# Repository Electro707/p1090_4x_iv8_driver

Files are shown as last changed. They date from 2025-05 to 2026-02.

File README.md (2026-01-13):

# P1090 - IV-8 Driver, 4x
\> PCBs (both), Rev 1
\> Firmware, Rev 1A (wip)
\> Enclosure, Rev 1

This project is a driver for 4xIV-8 VFD Tubes.

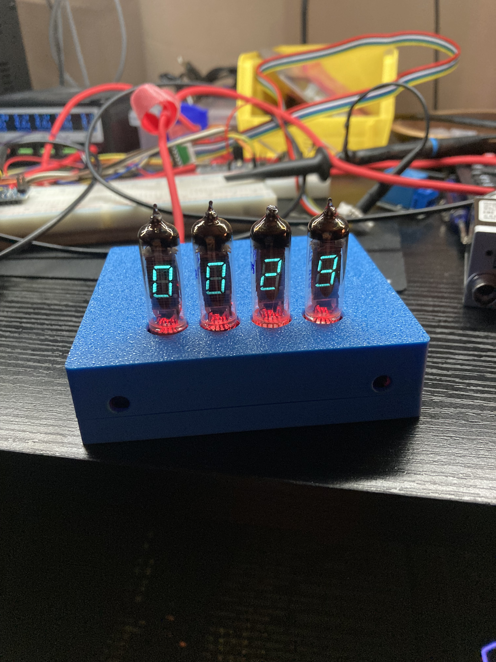
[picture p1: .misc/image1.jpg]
Project Image


# Directory Structure
- E1091: PCB, Driver board, KiCAD
- E1092: PCB, IV-8 Adapter Board, KiCAD
- F1093: Firmware, Arduino-IDE
- CAD: Enclosure, FreeCAD. All parts are under `C1094.FCStd`
    - C1094: Bottom Enclosure
    - C1095: Top Enclosure
    - C1096: Button Press Extender
    - C1097: Light Pipe for LED
- `release`: Latest exported build files, includes Schematic, BOM, Gerber, and STL files

# Firmware Doc

The document for the firmware can be found over at [https://electro707.com/documentation/Projects/F1093_docs/](https://electro707.com/documentation/Projects/F1093_docs/)

The document also describes the requirements for building the Firmware through the Arduino IDE.

To build the firmware, you will need to make a file `wifiDefault.h` in the firmrware's folder with the following WIFI credentials

```c
#ifndef WIFI_DEFAULT_H
#define WIFI_DEFAULT_H

#define DEFAULT_WIFI_SSID       "ENTER-SSID"
#define DEFAULT_WIFI_PASSWORD   "ENTER_PASS"

#endif
```

# Known Issues
> [!IMPORTANT]
> Please read the file linked below before attempting to build this hardware.

Known issues, and any workarounds, are documented in [ERRATA.md](ERRATA.md).

# todo:
- Buy or 3D print light-pipes for better LED-to-IV8 conductance

# License
This project is licensed under [GPLv3](LICENSE.md)**

** This excludes the files in `E1091_PCB_Driver/ExternalStep`, as they came from the manufacturer.

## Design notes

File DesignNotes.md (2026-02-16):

# Circuit Design Notes

These are notes on math for the boost converter (the only thing here). Some of the numbers are not for the current design, but for a fix on the audible noise issue (see [ERRATA.md](ERRATA.md)). The equations are still true though in any case.

## Boost output voltage

As designed:
$$
R_1 = R_2 * \left(\frac{V_{out}}{1.23}-1\right) \\
V_{out} = \frac{R1}{R2}+1*1.23\\
V_{out} = \frac{270k\Omega}{10k\Omega}+1*1.23\\
V_{out} = 34.44v
$$

## Load of grid and anode
This is taken from an IV-8 datasheet
$$
I_{anode_{max}} = 0.8mA + 1.7mA = 2.5mA \\
I_{grid_{max}} = 3mA + 2mA = 5mA
$$

## Duty Cycle
$$
V_{sw} = 0.2v \\
V_{diode} = 0.3v \\
$$

$$ \begin{align}
Duty &= \frac{V_{out}+V_{diode}-V_{in}}{V_{out}+V_{diode}-V_{sw}} \\
     &= \frac{34.44+0.3-5}{34.44+0.3-0.2} \\\
     &= 86.1\% \\
\end{align} $$

The 400Khz number is from the min spec of $F_{SW}$ for the Y variant
$$ \begin{align}
T_{period_{max}}  &= 1/400kHz \\
            &= 2.5uS \\
T_{on_{max}} &= T_{period_{max}} * Duty \\
            &= 2.15uS
\end{align} $$

## Minimum Inductance
At no or little load
$$ \begin{align}
L   &\geq V_{L} * \frac{dt}{dI} \\
    &\geq (V_{in}-V_{sw}) * \frac{dt}{dI} \\
    &\geq (5-0.2) * \frac{2.15uS}{1} \\
    &\geq 10uH
\end{align} $$

## High and Low Voltage

Used figure 25 of the datasheet to get the high and low current to ensure non-continuous mode

The additional load of 16mA is with a 2.2k parallel with the output to ensure always continuous mode

$$
\begin{align}
I_{load} &= (34.44 / 2.2k\Omega) + I_{anode_{max}} + I_{grid_{max}}  \\
        &=23.15mA \end{align} \\
L = 15uH
$$

$$ \begin{align}
V &= L * {d_i/d_t} \\
{d_i/d_t} &= V_{L}/L \\
 &= (5-0.2) / 47uH \\
 &= 0.102A/uS
\end{align} $$

$$ \begin{align}
I_{mid} &= \frac{I_{load}}{1-Duty} \\
    &= \frac{23.15mA}{1-0.861} \\
    &= 166mA \\
I_{\Delta} &= {d_i/d_t} * T_{on_{max}} \\
    &= 0.102A/uS * 2.15uS \\
    &= 219mA \\
I_{low} &= I_{mid} - I_{\Delta}/2 \\
        &= 56.5mA
I_{max} &= I_{mid} + I_{\Delta}/2 \\
        &= 275.5mA
\end{align} $$

## Load Current
$$
I_{sw_{max}} \geq 1A \\
\begin{align}
I_{load_{max}} &= (1-Duty) * (I_{sw_{max}} - \frac{Duty*(V_in)-V_{sw}}{2*f*L}) \\
             &= (1-0.861) * (1A - \frac{0.861*4.8}{2*400kHz*15uH}) \\
            &= 91.12mA
\end{align}
$$

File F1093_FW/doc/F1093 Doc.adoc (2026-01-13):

= F1093 - Large 7-Seg Display Firmware
rev 1-dev

:sectnums:

== Development Information

=== Setup
The following tools and libraries are used to build this firmware:

[%autowidth]
|===
|Type|Name|Revision

|IDE
|Arduino IDE
|2.3.2

|Arduino Board
|esp32 by Espressif
|3.3.5

|Arduino Library
|fastLED
|3.10.3
|===

==== Arduino Board Setup
The board setup (in the Tools tab) is setup as follows:

* Board: "ESP32 Dev Module"
* CPU Frequency: "240Mhz (WiFi/BT)"
* Core Debug Level: "None"
* Erase All Flash Before Sketch Upload: "Disabled"
* Events Run On: "Core 1"
* Flash Frequency: "40Mhz"
* Flash Mode: "QIO"
* Flash Size: "4MB (32Mb)"
* JTAG Adapter: "Disabled"
* Arduino Runs On: "Core 1"
* Partition Scheme: "Default 4MB with spiffs (1.2MB APP/1.5MB SPIFFS)"
* PSRAM: "Disabled"
* Upload Speed: "921600"
* Zigbee Mode: "Disabled"

=== Required File
To build this firmware, a file titled `wifiDefault.h` must be created in the firmware's root path. The file must contain the following:

```
#ifndef WIFI_DEFAULT_H
#define WIFI_DEFAULT_H

#define DEFAULT_WIFI_SSID       "ENTER-SSID"
#define DEFAULT_WIFI_PASSWORD   "ENTER_PASS"

#endif
```

== Functional Description
The F1093 firmware controls up 4x IV-8 Vacuum Fluorescent displays.

This firmware attempts to connect to a WIFI network on startup. The WIFI SSID and password are initially defined in a header file `wifiDefault.h`.

=== Display Modes
This firmware has the following run-time modes for the display:

* *"off"*: The displays are disabled, nothing is displayed
* *"numb"*: Shows a static number on the display. Useful for host updated numeric display
* *"time"*: Shows the current time based off the timezone set.

On startup the firmware defaults to "time"

=== Time Format

When displaying time, this firmware can present that in the following modes:

* *24hr*: Displays the time as HH:MM in 24-hour format
* *12hr*: Displays the time as HH:MM in 12-hour format. No AM/PM indicator can be shown in this mode
* *metric*: Displays the time as HH:MM in metric format. See https://metric-time.com/ for more information on this format

=== NVM
This firmware stores some parameters in non-volatile memory (nvm). The esp32-arduino's `EEPROM` is used, handling data storage and integrity.
The following table describes what is stored.

// [cols="1,1,1,3"]
[%autowidth]
|===
|Offset|Length|Type|Description

|0
|1
|byte
|NVM magic to see if something is written. Should be 0x5A

|1
|32
|str
|WIFI SSID to connect to

|33
|32
|str
|WIFI password to connect to

|===

=== Communication
This firmware can be communicated with over the following interfaces:

* Serial over USB, 115200 baud, 8N1
* TCP over Wifi, port 23

This firmware can handle both connections simultaneously.

All command frames sent to/from the device are in ASCII text mode, with either carriage-return (\r) or line-feed (\n) ending per frame.

==== Wifi
This firmware handles being connected over Telnet directly, allowing to connect to this firmware over the built-in `telnet` commands to many UNIX systems.

The following telnet commands are handled, some of which are automatically sent when starting a telnet session:

* DO
* WILL
* Interrupt Process, including waiting for timing-mark to responds with a new line and flush the internal receive buffer

This firmware also implements a "exit" command to close a Telnet connection.

This firmware set it's hostname to `esp32-f1093`.

==== Debug UART

A seperate debug UART exists, only accessible on the board over the tag-connect header. This is used for this firmware and ESP32's internal debugging.

If the C define `DEBUG_ENABLED` is set in `common.h`, all debug messages are passed through this interface.

[page-layout=landscape]
<<<

== Commands
The commands are mostly structured as verb-noun system; the verb dictates the action, and noun is what to apply the verb to. For example "get mode" requests to "get" the "mode".
The verb and noun are space delimited. Any argument(s) to the command are also space delimited.

If a command doesn't sent back a return value,
If a return value is not specified for a command, an acknowledgment (ACK) is sent back as the string "ok".
Any not-acknowledgments (NACK) are sent as "error: X", where X is a human description of the error. Any command can sent a NACK if the command failed to execute.

The following table list all commands supported.

// [%autowidth]
[cols="1,2,5,5,6"]
|===
|Verb|Noun|Arguments|Return|Desc

|ping
|
|
|pong!
|ping/pong. Useful for checking if the firmware is functional

.6+|set
|mode
a|[str], mode, either:

- 'off'
- 'numb'
- 'time'
|
|Set the new display mode, which is the same string as described in <<Display Modes>>

|n
|[int], The number to display to in "numb" mode
|ACK only if in "numb" mode
|

//|timezone
//|The timezone as the TZ identifier
//|ACK
//|

// |time
// |Either the current time in the format "HH:MM:SS", or "auto" to automatically fetch the time from the internet
// |
// |

|timeFormat
a|[str], The new time format, either:

- '24hr'
- '12hr'
- 'metric'
|
|Sets the displayed time format, which is the same string as described in <<Time Format>>

|uartBaud
|[int], The new baud rate
|
|Switches the main UART baud rate

|ledColor
a|[str], The new LED color mode, either:

- 'manual'
- 'rainbow'
- 'timeHue'
|
|Sets the LED color mode

|ledBlinkMode
a|[str], The new LED blink mode, either:

- 'off'
- 'sec'
|
|Sets the LED blink mode

.6+|get
|version
|
|The firmware version
|

|mode
|
|The current mode
|See <<Display Modes>>

|n
|
|The current displayed number
|

// |timezone
// |
// |The timezone as a TZ identifier
// |

|time
|
|The current time, in the set timezone
|

|timeFormat
|
|The time format
|See <<Time Format>>

|ip
|
|The current IP address, or "none" if not connected to WiFi
|

.4+|update
|begin
|The firmware size in bytes
|
|Starts a firmware update

|cont
|The number of bytes to send, then the raw bytes after reception of the first ACK
|ACK, followed by another ACK after raw bytes received
|When this command is received with the number of bytes to send, an ACK is sent. The firmware then expects
 that many bytes (not ASCII) to be received, in which another ACK will be sent after all expected bytes are received

|end
|
|
|Finishes the firmware update process

|cancel
|
|
|Cancels any on-going firmware update process

|exit
|
|
|
|In Telnet mode, this command sends the required Telnet commands to disconnect.

|reboot
|
|
|
|Restarts the ESP32
|===

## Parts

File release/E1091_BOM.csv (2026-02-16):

Qty | Reference | Description | Value | Footprint
4 | C1,C2,C8,C12 | Capacitor, 0.1uF, 0805 | 0.1uF | Capacitor_SMD:C_0805_2012Metric
1 | C6 | Capacitor, 4.7uF, 1206 | 4.7uF | Capacitor_SMD:C_1206_3216Metric
1 | C7 | Capacitor, 470nF, 0805 | 470nF | Capacitor_SMD:C_0805_2012Metric
1 | C10 | Capacitor, 82pF, 0805 | 82pF | Capacitor_SMD:C_0805_2012Metric
3 | C11,C13,C14 | Capacitor, 2.2uF, 0805 | 2.2uF | Capacitor_SMD:C_0805_2012Metric
1 | D1 | Diode, Shottkey, 40V, 500mA, SOD123 | MBR0540 | Diode_SMD:D_SOD-123
1 | D2 | Diode, TVS, 18.6V, SOD523 | ESD5Z5.0T1G | Diode_SMD:D_SOD-523
4 | D3,D4,D5,D6 | LED Diode, Addressable | WS2812B | LED_SMD:LED_WS2812B_PLCC4_5.0x5.0mm_P3.2mm
1 | F1 | Polyfuse, 500mA, 1206 |  | Fuse:Fuse_1206_3216Metric
1 | FB1 | 0ZCJ0050FF2G | FerriteBead | Inductor_SMD:L_0805_2012Metric
0 | J1 | Header, UART, 3POS 0.1" | Conn_01x03 | Connector_PinSocket_2.54mm:PinSocket_1x03_P2.54mm_Vertical
1 | J3 | Connector, USB C | USB4085 | Connector_USB:USB_C_Receptacle_GCT_USB4085
1 | L1 | Inductor, 15uH, 1210 | CBC3225T150KR | Inductor_SMD:L_1210_3225Metric
12 | Q7,Q8,Q9,Q10,Q11,Q12,Q13,Q14,Q15,Q16,Q18,Q19 | Transistor, P-Channel MOSFET | BSS84 | Package_TO_SOT_SMD:SOT-23
0 | R1 | Resistor, Jumper, 0805 | 0 | Resistor_SMD:R_0805_2012Metric
2 | R2,R3 | Resistor, 5.1k?, 0805 | 5.1k | Resistor_SMD:R_0805_2012Metric
2 | R4,R14 | Resistor, Jumper, 0805 | 0 | Resistor_SMD:R_0805_2012Metric
11 | R5,R9,R10,R11,R12,R15,R16,R17,R19,R41,R58 | Resistor, 10k?, 0805 | 10k | Resistor_SMD:R_0805_2012Metric
1 | R13 | Resistor, 270k?, 0805 | 270k | Resistor_SMD:R_0805_2012Metric
1 | R18 | Resistor, 1k?, 0805 | 1k | Resistor_SMD:R_0805_2012Metric
1 | RV2 | Potentiometer, 100?, 12 Turn | 3266Y-1-101LF | Potentiometer_THT:Potentiometer_Bourns_3266W_Vertical,Resistor_SMD:R_0805_2012Metric
24 | R20,R21,R22,R23,R24,R25,R26,R27,R28,R29,R30,R31,R32,R33,R34,R35,R36,R37,R38,R39,R42,R43,R44,R45 | Resistor, 20k?, 0805 | 20k | Resistor_SMD:R_0805_2012Metric
12 | R46,R47,R48,R49,R50,R51,R52,R53,R54,R55,R56,R57 | Resistor, 100k?, 0805 | 100k | Resistor_SMD:R_0805_2012Metric
2 | SW1,SW2 | Pushbutton, Tactile, Right-angle | Y97HS12A2VAFP | Button_Switch_THT:SW_Tactile_SPST_Angled_PTS645Vx83-2LFS
4 | T1,T2,T3,T4 |  | ~ | ProjectFoot:IV-8 Adapter
0 | TP2,TP3,TP4,TP5 |  | TestPoint | TestPoint:TestPoint_Keystone_5005-5009_Compact
1 | U2 | IC, UART to USB Bridge | CH340N | Package_SO:SOP-8_3.9x4.9mm_P1.27mm
0 | U4 (OLD, DoNotUse) |  | LMV358 | Package_SO:SOIC-8_3.9x4.9mm_P1.27mm
1 | U4 | IC, Op-Amp, Rail-to-Rail, 250mA | AD8532AR | Package_SO:SOIC-8_3.9x4.9mm_P1.27mm
1 | U5 | IC, Shift Register | 74HC595 | Package_SO:SOIC-16_3.9x9.9mm_P1.27mm
2 | U6,U8 | IC, Darlington Pair | ULN2003 | Package_SO:SOIC-16_3.9x9.9mm_P1.27mm
1 | U7 | IC, Boost Converter | LM2733YMF | Package_TO_SOT_SMD:SOT-23-5
1 | U9 | IC, Linear Regulator, 3.3v | NCP1117-3.3_SOT223 | Package_TO_SOT_SMD:SOT-223-3_TabPin2
1 | U10 | IC, Microntroller+Wifi+BLE | ESP32-WROOM-32E | RF_Module:ESP32-WROOM-32D

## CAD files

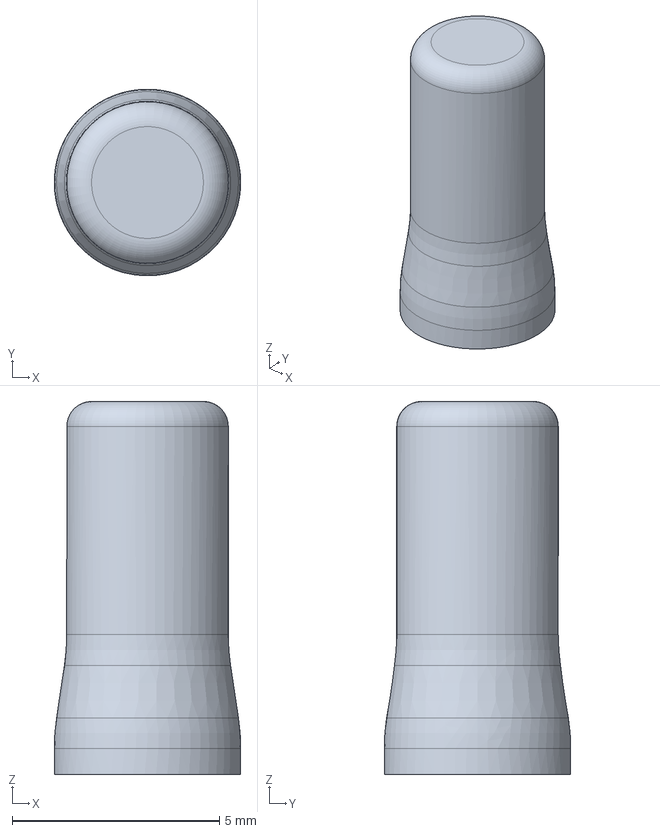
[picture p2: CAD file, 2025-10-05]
C1094-5/C1094.FCStd
4.50 x 4.50 x 9.00 mm

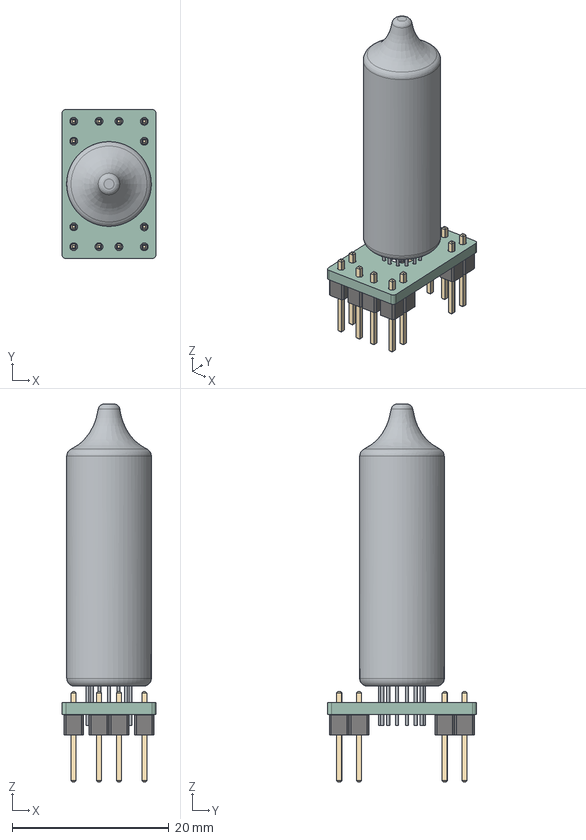
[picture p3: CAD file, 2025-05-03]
E1092_PCB_IV-8/E1092_RevA1.step
12.0 x 19.0 x 48.2 mm
IV-8-Body_CUT
PinHeader_1x02_P2.54mm_Vertical x 6
IV-11Mounting_PCB

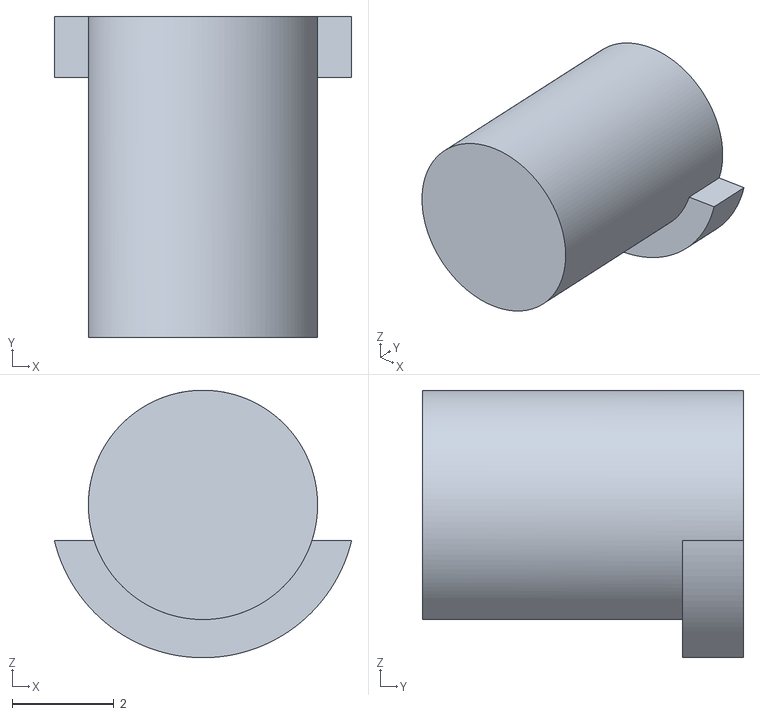
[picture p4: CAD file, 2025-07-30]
release/C1096Rev1.stl
5.83 x 6.30 x 5.25

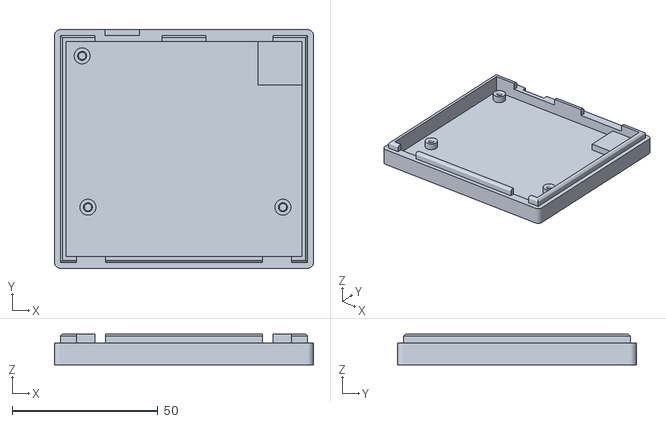
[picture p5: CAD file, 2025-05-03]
release/C1094Rev1.stl
89.0 x 82.0 x 10.6

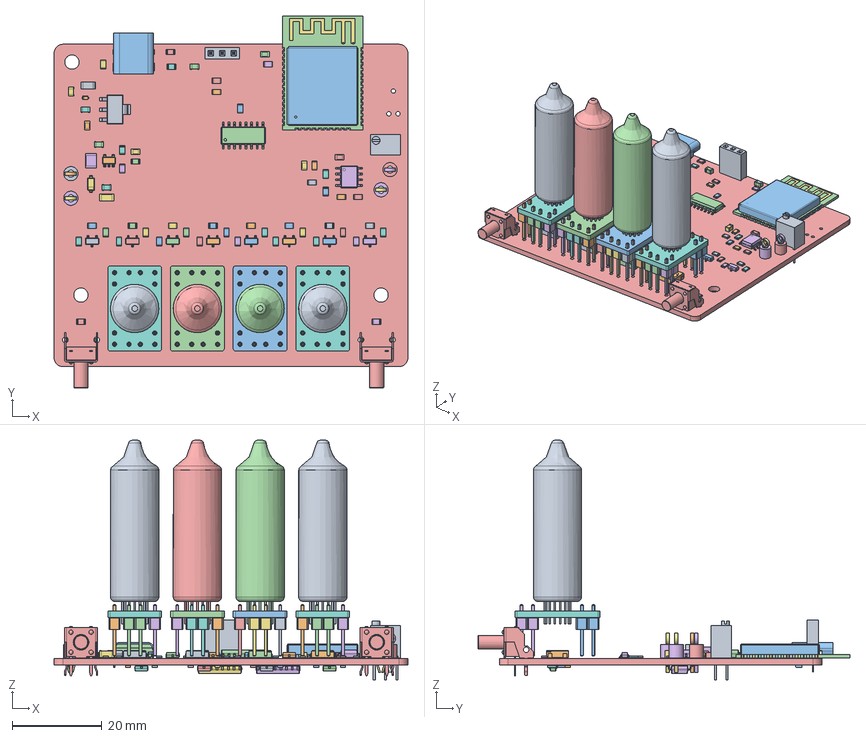
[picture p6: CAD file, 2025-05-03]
C1094-5/PCB.FCStd
79.0 x 83.0 x 53.5 mm
R_0805_2012Metric
LED_WS2812B_PLCC4_5.0x5.0mm_P3.2mm
R_0805_2012Metric001
C_0805_2012Metric
R_0805_2012Metric002
R_0805_2012Metric003
C_1206_3216Metric
R_0805_2012Metric004
placementOutline^Submodel-noModelForPart_GND_PAD_6X6_498584182_Submodel-GND_PAD_6X6_498584182_part_DesignRootModel_PCB_ESP32-WROOM-32D_V2(2)_PCB_ESP32-WROOM-32D
DFN1006.STEP^DFN1006.STEP_Submodel-SOD882_part_DesignRootModel_PCB_ESP32-WROOM-32D_V2(2)_PCB_ESP32-WROOM-32D_V2
R0201_20210301.STEP^R0201_20210301.STEP_Submodel-R0201_part_DesignRootModel_PCB_ESP32-WROOM-32D_V2(2)_PCB_ESP32-WROOM-32D_V2
R0201_20210301.STEP^R0201_20210301.STEP_Submodel-R0201_part_DesignRootModel_PCB_ESP32-WROOM-32D_V2(2)_PCB_ESP32-WROOM-32D_V003
R0201_20210301.STEP^R0201_20210301.STEP_Submodel-R0201_part_DesignRootModel_PCB_ESP32-WROOM-32D_V2(2)_PCB_ESP32-WROOM-32D_V004
R0201_20210301.STEP^R0201_20210301.STEP_Submodel-R0201_part_DesignRootModel_PCB_ESP32-WROOM-32D_V2(2)_PCB_ESP32-WROOM-32D_V006
R0201_20210301.STEP^R0201_20210301.STEP_Submodel-R0201_part_DesignRootModel_PCB_ESP32-WROOM-32D_V2(2)_PCB_ESP32-WROOM-32D_V007
R0201_20210301.STEP^R0201_20210301.STEP_Submodel-R0201_part_DesignRootModel_PCB_ESP32-WROOM-32D_V2(2)_PCB_ESP32-WROOM-32D_V008
R0201_20210301.STEP^R0201_20210301.STEP_Submodel-R0201_part_DesignRootModel_PCB_ESP32-WROOM-32D_V2(2)_PCB_ESP32-WROOM-32D_V010
R0201_20210301.STEP^R0201_20210301.STEP_Submodel-R0201_part_DesignRootModel_PCB_ESP32-WROOM-32D_V2(2)_PCB_ESP32-WROOM-32D_V011
R0201_20210301.STEP^R0201_20210301.STEP_Submodel-R0201_part_DesignRootModel_PCB_ESP32-WROOM-32D_V2(2)_PCB_ESP32-WROOM-32D_V012
L0201_20210301.STEP^L0201_20210301.STEP_Submodel-L0201_part_DesignRootModel_PCB_ESP32-WROOM-32D_V2(2)_PCB_ESP32-WROOM-32D_V2
L0201_20210301.STEP^L0201_20210301.STEP_Submodel-L0201_part_DesignRootModel_PCB_ESP32-WROOM-32D_V2(2)_PCB_ESP32-WROOM-32D_V003
C0201_20210301.STEP^C0201_20210301.STEP_Submodel-C0201_part_DesignRootModel_PCB_ESP32-WROOM-32D_V2(2)_PCB_ESP32-WROOM-32D_V2
C0201_20210301.STEP^C0201_20210301.STEP_Submodel-C0201_part_DesignRootModel_PCB_ESP32-WROOM-32D_V2(2)_PCB_ESP32-WROOM-32D_V003
C0201_20210301.STEP^C0201_20210301.STEP_Submodel-C0201_part_DesignRootModel_PCB_ESP32-WROOM-32D_V2(2)_PCB_ESP32-WROOM-32D_V004
C0201_20210301.STEP^C0201_20210301.STEP_Submodel-C0201_part_DesignRootModel_PCB_ESP32-WROOM-32D_V2(2)_PCB_ESP32-WROOM-32D_V005
C0201_20210301.STEP^C0201_20210301.STEP_Submodel-C0201_part_DesignRootModel_PCB_ESP32-WROOM-32D_V2(2)_PCB_ESP32-WROOM-32D_V006
C0201_20210301.STEP^C0201_20210301.STEP_Submodel-C0201_part_DesignRootModel_PCB_ESP32-WROOM-32D_V2(2)_PCB_ESP32-WROOM-32D_V007
C0201_20210301.STEP^C0201_20210301.STEP_Submodel-C0201_part_DesignRootModel_PCB_ESP32-WROOM-32D_V2(2)_PCB_ESP32-WROOM-32D_V008
C0201_20210301.STEP^C0201_20210301.STEP_Submodel-C0201_part_DesignRootModel_PCB_ESP32-WROOM-32D_V2(2)_PCB_ESP32-WROOM-32D_V009
C0201_20210301.STEP^C0201_20210301.STEP_Submodel-C0201_part_DesignRootModel_PCB_ESP32-WROOM-32D_V2(2)_PCB_ESP32-WROOM-32D_V010
C0201_20210301.STEP^C0201_20210301.STEP_Submodel-C0201_part_DesignRootModel_PCB_ESP32-WROOM-32D_V2(2)_PCB_ESP32-WROOM-32D_V011
C0201_20210301.STEP^C0201_20210301.STEP_Submodel-C0201_part_DesignRootModel_PCB_ESP32-WROOM-32D_V2(2)_PCB_ESP32-WROOM-32D_V012
C0201_20210301.STEP^C0201_20210301.STEP_Submodel-C0201_part_DesignRootModel_PCB_ESP32-WROOM-32D_V2(2)_PCB_ESP32-WROOM-32D_V013
C0201_20210301.STEP^C0201_20210301.STEP_Submodel-C0201_part_DesignRootModel_PCB_ESP32-WROOM-32D_V2(2)_PCB_ESP32-WROOM-32D_V014
C0201_20210301.STEP^C0201_20210301.STEP_Submodel-C0201_part_DesignRootModel_PCB_ESP32-WROOM-32D_V2(2)_PCB_ESP32-WROOM-32D_V015
C0201_20210301.STEP^C0201_20210301.STEP_Submodel-C0201_part_DesignRootModel_PCB_ESP32-WROOM-32D_V2(2)_PCB_ESP32-WROOM-32D_V016
C0201_20210301.STEP^C0201_20210301.STEP_Submodel-C0201_part_DesignRootModel_PCB_ESP32-WROOM-32D_V2(2)_PCB_ESP32-WROOM-32D_V017
SOIC8_208_20210301.STEP^SOIC8_208_20210301.STEP_Submodel-SOIC08-WN_part_DesignRootModel_PCB_ESP32-WROOM-32D_V2(2)_PCB_ESP32-WROOM-32D_V2
SOIC8_208_20210301.STEP^SOIC8_208_20210301.STEP_Submodel-SOIC08-WN_part_DesignRootModel_PCB_ESP32-WROOM-32D_V2(2)_PCB_ESP32-WROOM-32D_V003
SOIC8_208_20210301.STEP^SOIC8_208_20210301.STEP_Submodel-SOIC08-WN_part_DesignRootModel_PCB_ESP32-WROOM-32D_V2(2)_PCB_ESP32-WROOM-32D_V004
SOIC8_208_20210301.STEP^SOIC8_208_20210301.STEP_Submodel-SOIC08-WN_part_DesignRootModel_PCB_ESP32-WROOM-32D_V2(2)_PCB_ESP32-WROOM-32D_V005
SOIC8_208_20210301.STEP^SOIC8_208_20210301.STEP_Submodel-SOIC08-WN_part_DesignRootModel_PCB_ESP32-WROOM-32D_V2(2)_PCB_ESP32-WROOM-32D_V006
SOIC8_208_20210301.STEP^SOIC8_208_20210301.STEP_Submodel-SOIC08-WN_part_DesignRootModel_PCB_ESP32-WROOM-32D_V2(2)_PCB_ESP32-WROOM-32D_V007
SOIC8_208_20210301.STEP^SOIC8_208_20210301.STEP_Submodel-SOIC08-WN_part_DesignRootModel_PCB_ESP32-WROOM-32D_V2(2)_PCB_ESP32-WROOM-32D_V008
SOIC8_208_20210301.STEP^SOIC8_208_20210301.STEP_Submodel-SOIC08-WN_part_DesignRootModel_PCB_ESP32-WROOM-32D_V2(2)_PCB_ESP32-WROOM-32D_V009
SOIC8_208_20210301.STEP^SOIC8_208_20210301.STEP_Submodel-SOIC08-WN_part_DesignRootModel_PCB_ESP32-WROOM-32D_V2(2)_PCB_ESP32-WROOM-32D_V010
trace_1^Submodel-ANT_2P_1501846164_part_DesignRootModel_PCB_ESP32-WROOM-32D_V2(2)_PCB_ESP32-WROOM-32D_V2
ESP32_5x5_20210301.STEP^ESP32_5x5_20210301.STEP_Submodel-SLP48_5X5_part_DesignRootModel_PCB_ESP32-WROOM-32D_V2(2)_PCB_ESP32-WROOM-32D_V2
ESP32_5x5_20210301.STEP^ESP32_5x5_20210301.STEP_Submodel-SLP48_5X5_part_DesignRootModel_PCB_ESP32-WROOM-32D_V2(2)_PCB_ESP32-WROOM-32D_V003
XTAL3225_20210301.STEP^XTAL3225_20210301.STEP_Submodel-3225_part_DesignRootModel_PCB_ESP32-WROOM-32D_V2(2)_PCB_ESP32-WROOM-32D_V2
XTAL3225_20210301.STEP^XTAL3225_20210301.STEP_Submodel-3225_part_DesignRootModel_PCB_ESP32-WROOM-32D_V2(2)_PCB_ESP32-WROOM-32D_V003
XTAL3225_20210301.STEP^XTAL3225_20210301.STEP_Submodel-3225_part_DesignRootModel_PCB_ESP32-WROOM-32D_V2(2)_PCB_ESP32-WROOM-32D_V004
XTAL3225_20210301.STEP^XTAL3225_20210301.STEP_Submodel-3225_part_DesignRootModel_PCB_ESP32-WROOM-32D_V2(2)_PCB_ESP32-WROOM-32D_V005
XTAL3225_20210301.STEP^XTAL3225_20210301.STEP_Submodel-3225_part_DesignRootModel_PCB_ESP32-WROOM-32D_V2(2)_PCB_ESP32-WROOM-32D_V006
C0402_20210301.STEP^C0402_20210301.STEP_Submodel-0402A_part_DesignRootModel_PCB_ESP32-WROOM-32D_V2(2)_PCB_ESP32-WROOM-32D_V2
C0402_20210301.STEP^C0402_20210301.STEP_Submodel-0402A_part_DesignRootModel_PCB_ESP32-WROOM-32D_V2(2)_PCB_ESP32-WROOM-32D_V003
C0201_20210301.STEP^C0201_20210301.STEP_Submodel-C0201_part_DesignRootModel_PCB_ESP32-WROOM-32D_V2(2)_PCB_ESP32-WROOM-32D_V018
uid__4-175^DesignRootModel_PCB_ESP32-WROOM-32D_V2(2)_PCB_ESP32-WROOM-32D_V2
uid__1-346^DesignRootModel_PCB_ESP32-WROOM-32D_V2(2)_PCB_ESP32-WROOM-32D_V2
uid__1-355^DesignRootModel_PCB_ESP32-WROOM-32D_V2(2)_PCB_ESP32-WROOM-32D_V2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

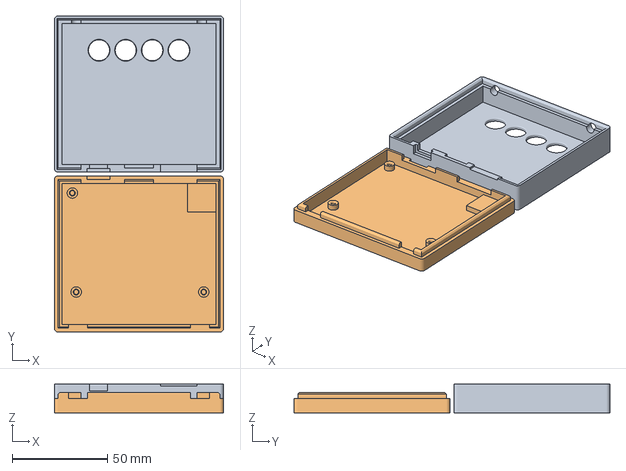
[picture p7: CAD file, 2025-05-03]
release/C1095Rev1.3mf
89.0 x 166.0 x 15.0 mm
B1095RevA1.stl
B1094RevA1.stl

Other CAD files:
C1094-5/Assembly.FCStd
release/C1095Rev1.stl

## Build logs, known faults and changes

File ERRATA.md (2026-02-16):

# Purpose
This document describes the hardware erratas and any potential fix using said hardware.

# E1091 Rev 1: Driver Board

## Op-Amp
The op-amp chosen cannot drive all 4 filaments of the IV-8 VFD tubes, and the initial 1k potentiometer value is too high

### Fix
- Use AD8532AR for the op-amp (U4)
- Use 3266Y-1-101LF for the pot RV2. You may have to bend the leads to get them to fit, but fit they will

The above changes are reflected in the BOM, but not the schematic PDF.

## High Pitch Boost Converter Noise
The boost converter generates audible-frequency high-pitch noise, which is unpleasant to have around.

### Cause Theory
- My guess is the boost converter goes in discontinuous output due to the low current draw (I think ~7mA if the datasheet for the IN-8 tubes are correct)
    - For now I replaced the inductor with a 47uH and added a 2.2kOhm load resistor in order to have the converter not go in discontinuous mode. Still ringing
- The capacitors are singing, downconverting any higher-frequency oscillation to baseband audio. Need to try out replacing the capacitors with non-mlcc if possible

### Fix
Not available, WIP

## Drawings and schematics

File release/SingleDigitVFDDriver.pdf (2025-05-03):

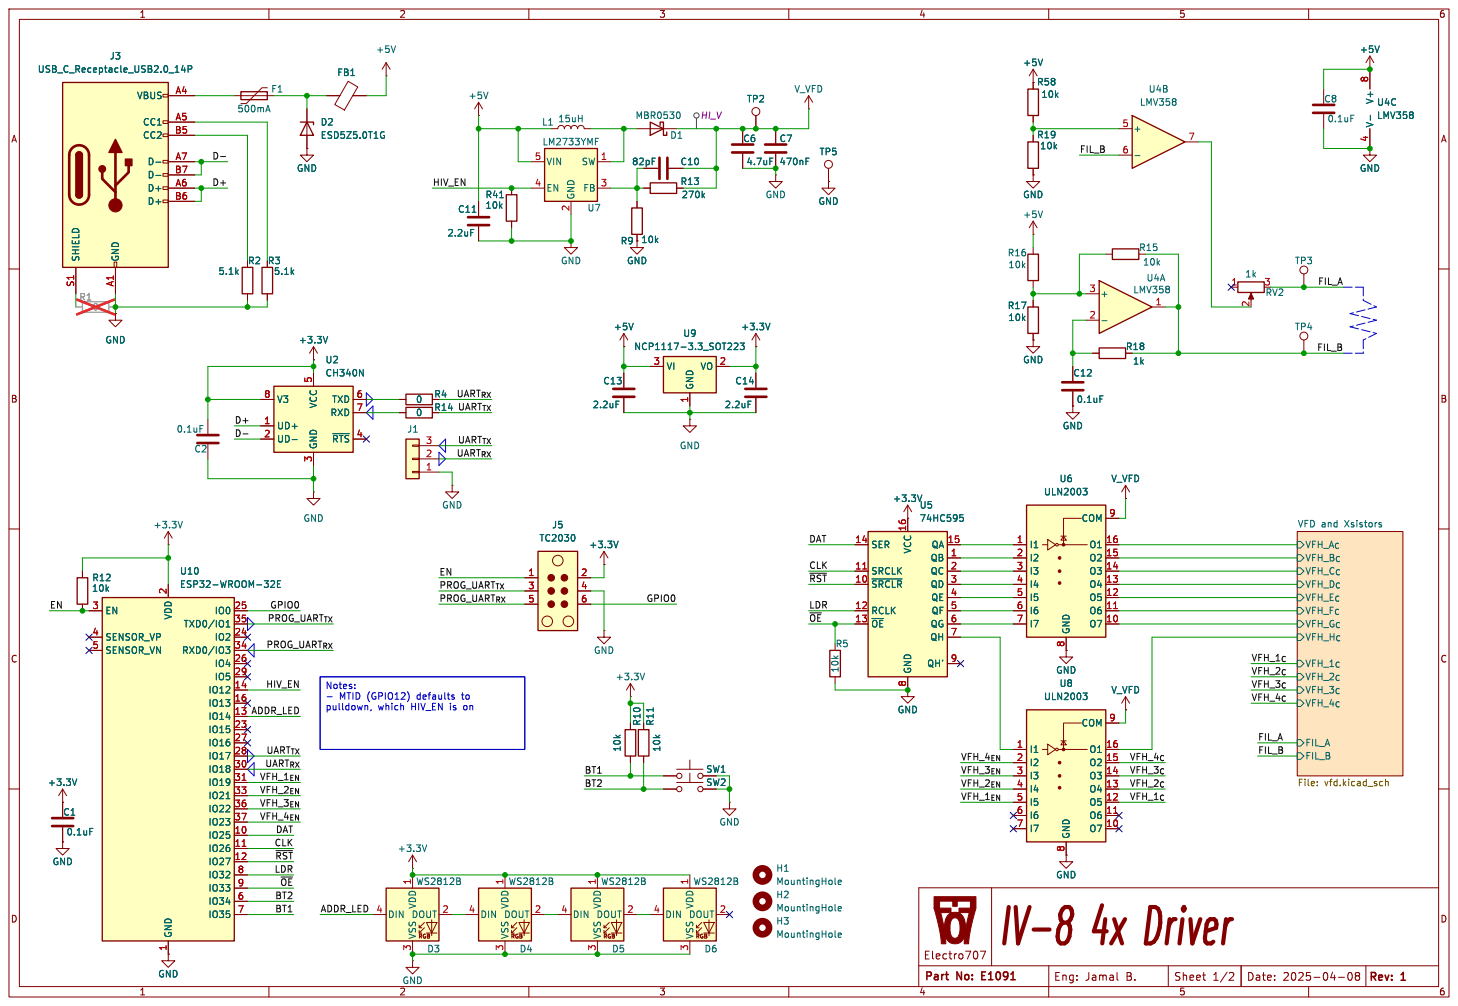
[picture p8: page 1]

V_VFD GND
VFH_4_{C} VFD and Xsistors File: vfd.kicad_sch

3 TXD 6 RXD 7 ~{RTS}4 U2 CH340N GND

8 QA 15 QB 1 QC 2 QD 3 QE 4 QF 5 QG 6 QH 7 QH' 9 GND

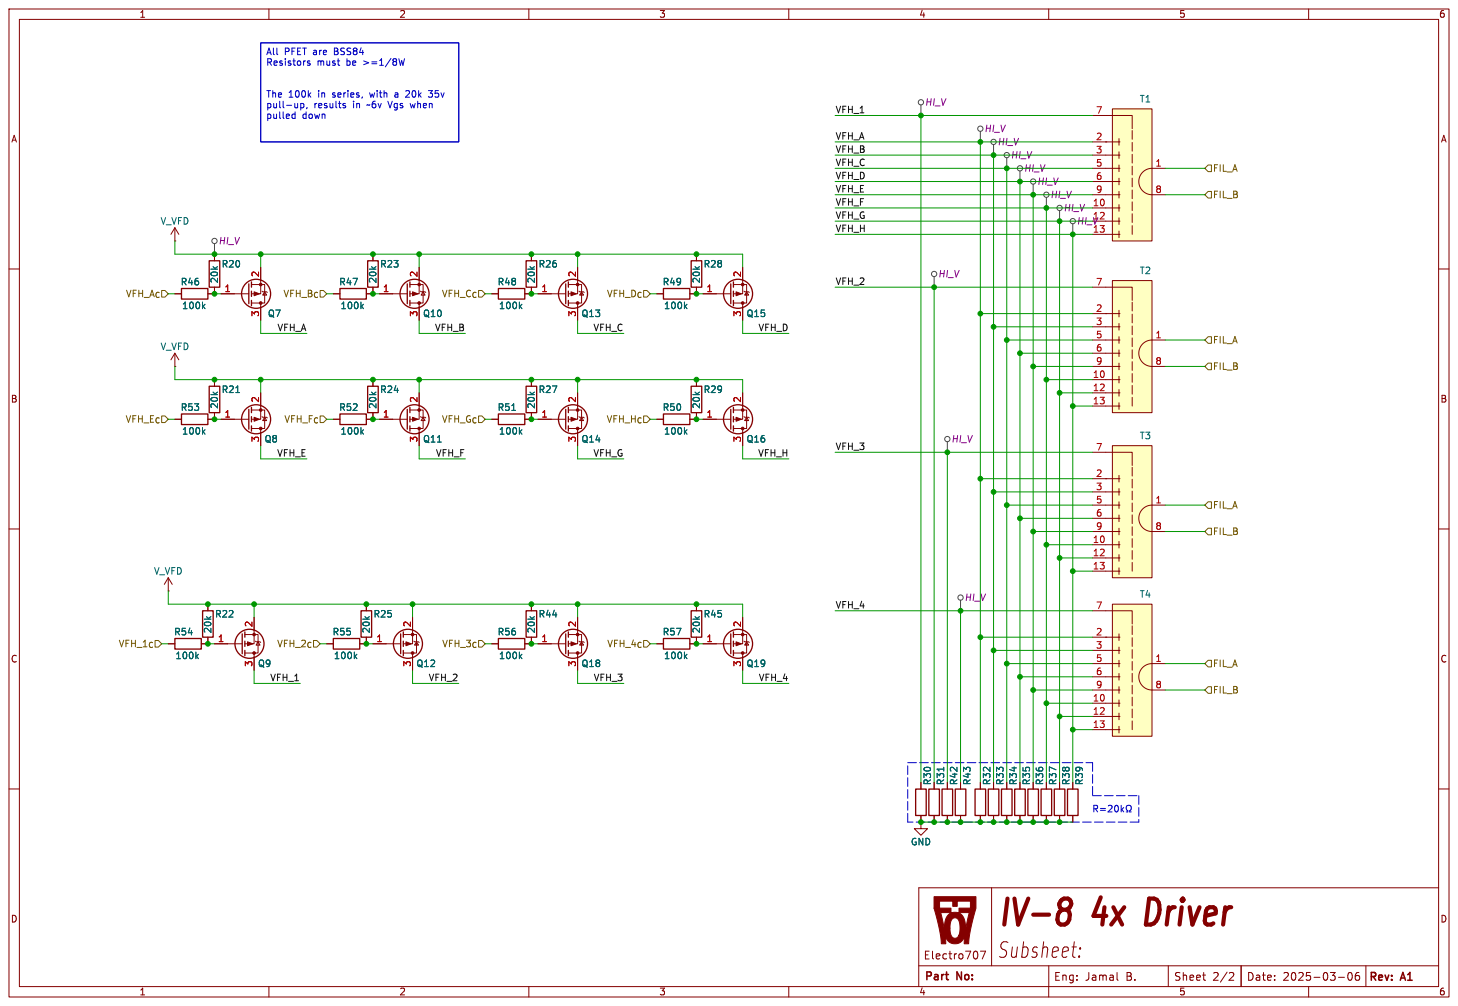
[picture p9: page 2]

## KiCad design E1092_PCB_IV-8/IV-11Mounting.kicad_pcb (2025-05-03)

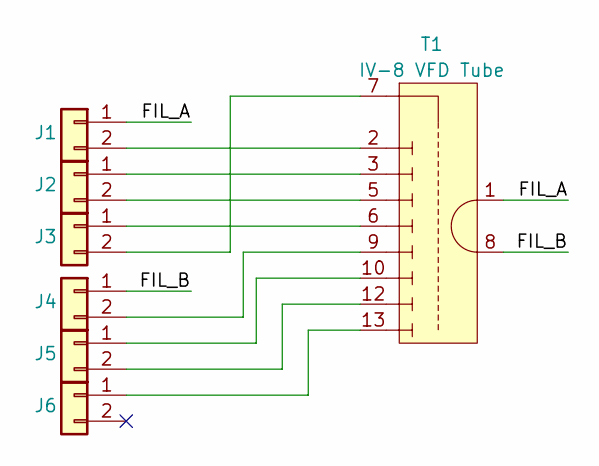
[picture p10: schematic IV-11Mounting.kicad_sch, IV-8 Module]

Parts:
J1, J2, J3, J4, J5, J6: Conn_01x02; PinHeader_1x02_P2.54mm_Vertical
T1: IV-8 VFD Tube; IV-8 VFD

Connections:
/FIL_A: J1.1, T1.1
/FIL_B: J4.1, T1.8
unnamed: J1.2, T1.2
unnamed: J2.1, T1.3
unnamed: J2.2, T1.5
unnamed: J3.1, T1.6
unnamed: J3.2, T1.7
unnamed: J4.2, T1.9
unnamed: J5.1, T1.10
unnamed: J5.2, T1.12
unnamed: J6.1, T1.13

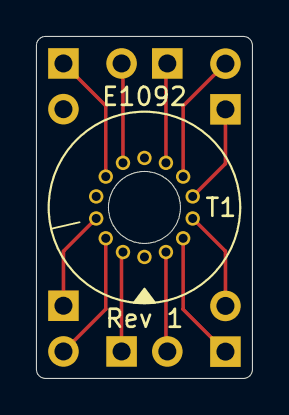
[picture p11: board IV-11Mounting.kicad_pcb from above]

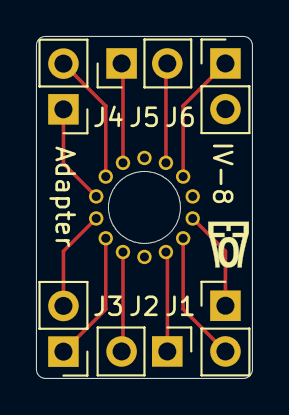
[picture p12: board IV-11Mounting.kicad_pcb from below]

Board: 2 copper layers, 12.0 x 19.0 mm, 7 parts (6 on the bottom side), 11 nets.

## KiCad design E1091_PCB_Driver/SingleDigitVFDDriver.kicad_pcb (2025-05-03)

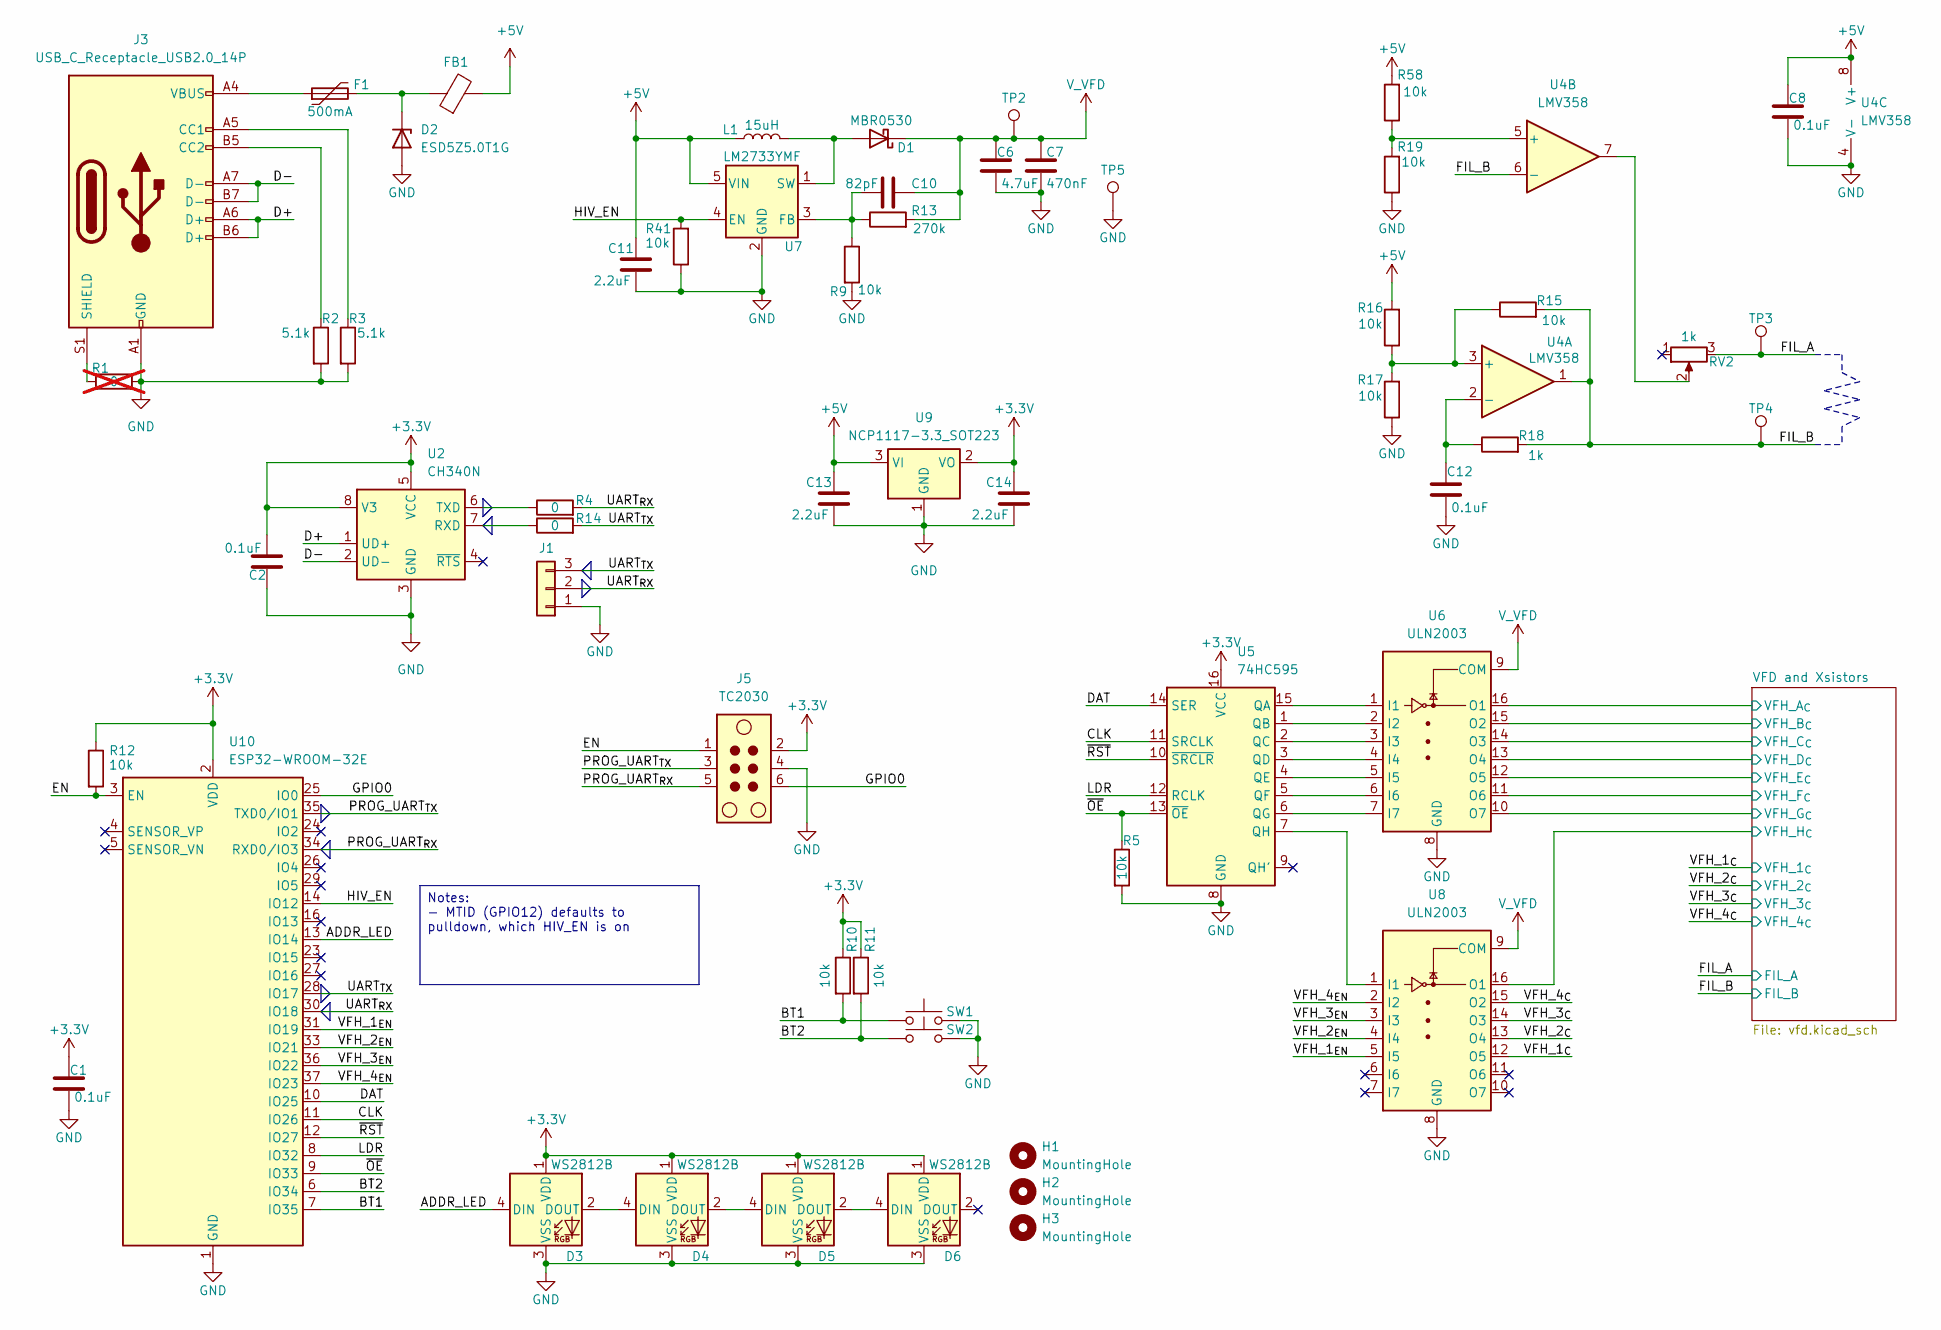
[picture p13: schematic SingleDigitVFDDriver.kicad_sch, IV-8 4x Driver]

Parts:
C1, C2, C8, C12: 0.1uF; C_0805_2012Metric
C6: 4.7uF; C_1206_3216Metric
C7: 470nF; C_0805_2012Metric
C10: 82pF; C_0805_2012Metric
C11, C13, C14: 2.2uF; C_0805_2012Metric
D1: MBR0530; D_SOD-123
D2: ESD5Z5.0T1G; D_SOD-523
D3, D4, D5, D6: WS2812B; LED_WS2812B_PLCC4_5.0x5.0mm_P3.2mm
F1: 500mA; Fuse_1206_3216Metric
FB1: FerriteBead; L_0805_2012Metric
H1, H2, H3: MountingHole; MountingHole_3.2mm_M3_DIN965
J1: Conn_01x03; PinSocket_1x03_P2.54mm_Vertical
J3: USB_C_Receptacle_USB2.0_14P; USB_C_Receptacle_GCT_USB4085
J5: TC2030; Tag-Connect_TC2030-IDC-NL_2x03_P1.27mm_Vertical
L1: 15uH; L_1210_3225Metric
R1: 0; R_0805_2012Metric; not fitted
R2, R3: 5.1k; R_0805_2012Metric
R4, R14: 0; R_0805_2012Metric
R5, R9, R10, R11, R12, R15, R16, R17, R19, R41, R58: 10k; R_0805_2012Metric
R13: 270k; R_0805_2012Metric
R18: 1k; R_0805_2012Metric
RV2: 1k; Potentiometer_Bourns_3266W_Vertical
SW1, SW2: SW_Push; SW_Tactile_SPST_Angled_PTS645Vx83-2LFS
TP2, TP3, TP4, TP5: TestPoint; TestPoint_Keystone_5005-5009_Compact
U2: CH340N; SOP-8_3.9x4.9mm_P1.27mm
U4: LMV358; SOIC-8_3.9x4.9mm_P1.27mm
U5: 74HC595; SOIC-16_3.9x9.9mm_P1.27mm
U6, U8: ULN2003; SOIC-16_3.9x9.9mm_P1.27mm
U7: LM2733YMF; SOT-23-5
U9: NCP1117-3.3_SOT223; SOT-223-3_TabPin2
U10: ESP32-WROOM-32E; ESP32-WROOM-32D

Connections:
+3.3V: C1.1, C2.2, C14.1, D3.1 (VDD), D4.1 (VDD), D5.1 (VDD), D6.1 (VDD), J5.2, R10.1, R11.1, R12.1, U2.5 (VCC), U2.8 (V3), U5.16 (VCC), U9.2 (VO), U10.2 (VDD)
+5V: C8.1, C11.1, C13.1, FB1.2, L1.1, R16.2, R58.2, U4.8 (V+), U7.5 (VIN), U9.3 (VI)
/ADDR_LED: D3.4 (DIN), U10.13 (IO14)
/BT1: R10.2, SW1.1, U10.7 (IO35)
/BT2: R11.2, SW2.1, U10.6 (IO34)
/CLK: U5.11 (SRCLK), U10.11 (IO26)
/D+: J3.A6 (D+), J3.B6 (D+), U2.1 (UD+)
/D-: J3.A7 (D-), J3.B7 (D-), U2.2 (UD-)
/DAT: U5.14 (SER), U10.10 (IO25)
/EN: J5.1, R12.2, U10.3 (EN)
/FIL_A: RV2.3, TP3.1; also elsewhere on the board
/FIL_B: R15.2, R18.2, TP4.1, U4.1, U4.6 (-); also elsewhere on the board
/GPIO0: J5.6, U10.25 (IO0)
/HIV_EN: R41.2, U7.4 (EN), U10.14 (IO12)
/LDR: U5.12 (RCLK), U10.8 (IO32)
/PROG_UART_{RX}: J5.5, U10.34 (RXD0/IO3)
/PROG_UART_{TX}: J5.3, U10.35 (TXD0/IO1)
/UART_{RX}: J1.2, R4.2, U10.30 (IO18)
/UART_{TX}: J1.3, R14.2, U10.28 (IO17)
/VFD and Xsistors/VFH_A_{C}: U6.16 (O1); also elsewhere on the board
/VFD and Xsistors/VFH_B_{C}: U6.15 (O2); also elsewhere on the board
/VFD and Xsistors/VFH_C_{C}: U6.14 (O3); also elsewhere on the board
/VFD and Xsistors/VFH_D_{C}: U6.13 (O4); also elsewhere on the board
/VFD and Xsistors/VFH_E_{C}: U6.12 (O5); also elsewhere on the board
/VFD and Xsistors/VFH_F_{C}: U6.11 (O6); also elsewhere on the board
/VFD and Xsistors/VFH_G_{C}: U6.10 (O7); also elsewhere on the board
/VFD and Xsistors/VFH_H_{C}: U8.16 (O1); also elsewhere on the board
/VFH_1_{C}: U8.12 (O5); also elsewhere on the board
/VFH_1_{EN}: U8.5 (I5), U10.31 (IO19)
/VFH_2_{C}: U8.13 (O4); also elsewhere on the board
/VFH_2_{EN}: U8.4 (I4), U10.33 (IO21)
/VFH_3_{C}: U8.14 (O3); also elsewhere on the board
/VFH_3_{EN}: U8.3 (I3), U10.36 (IO22)
/VFH_4_{C}: U8.15 (O2); also elsewhere on the board
/VFH_4_{EN}: U8.2 (I2), U10.37 (IO23)
/~OE: R5.1, U5.13 (~OE), U10.9 (IO33)
/~RST: U5.10 (~SRCLR), U10.12 (IO27)
GND: C1.2, C2.1, C6.2, C7.2, C8.2, C11.2, C12.2, C13.2, C14.2, D2.2 (A), D3.3 (VSS), D4.3 (VSS), D5.3 (VSS), D6.3 (VSS), J1.1, J3.A1 (GND), J3.A12 (GND), J3.B1 (GND), J3.B12 (GND), J5.4, R1.2, R2.2, R3.2, R5.2, R9.2, R17.1, R19.1, R41.1, SW1.2, SW2.2, TP5.1, U2.3 (GND), U4.4 (V-), U5.8 (GND), U6.8 (GND), U7.2 (GND), U8.8 (GND), U9.1 (GND), U10.1 (GND), U10.15 (GND), U10.38 (GND), U10.39 (GND); also elsewhere on the board
unnamed: D1.2 (A), L1.2, U7.1 (SW)
unnamed: D2.1 (K), F1.2, FB1.1
unnamed: D3.2 (DOUT), D4.4 (DIN)
unnamed: D4.2 (DOUT), D5.4 (DIN)
unnamed: D5.2 (DOUT), D6.4 (DIN)
unnamed: F1.1, J3.A4 (VBUS), J3.A9 (VBUS), J3.B4 (VBUS), J3.B9 (VBUS)
unnamed: J3.A5 (CC1), R3.1
unnamed: J3.B5 (CC2), R2.1
unnamed: J3.S1 (SHIELD), R1.1
unnamed: RV2.2, U4.7
unnamed: R14.1, U2.7 (RXD)
unnamed: R4.1, U2.6 (TXD)
unnamed: R15.1, R16.1, R17.2, U4.3 (+)
unnamed: C12.1, R18.1, U4.2 (-)
unnamed: R19.2, R58.1, U4.5 (+)
unnamed: U5.15 (QA), U6.1 (I1)
unnamed: U5.1 (QB), U6.2 (I2)
unnamed: U5.2 (QC), U6.3 (I3)
unnamed: U5.3 (QD), U6.4 (I4)
unnamed: U5.4 (QE), U6.5 (I5)
unnamed: U5.5 (QF), U6.6 (I6)
unnamed: U5.6 (QG), U6.7 (I7)
unnamed: U5.7 (QH), U8.1 (I1)
unnamed: C10.1, R9.1, R13.1, U7.3 (FB)
V_VFD: C6.1, C7.1, C10.2, D1.1 (K), R13.2, TP2.1, U6.9 (COM), U8.9 (COM); also elsewhere on the board

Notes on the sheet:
Notes: - MTID (GPIO12) defaults to pulldown, which HIV_EN is on

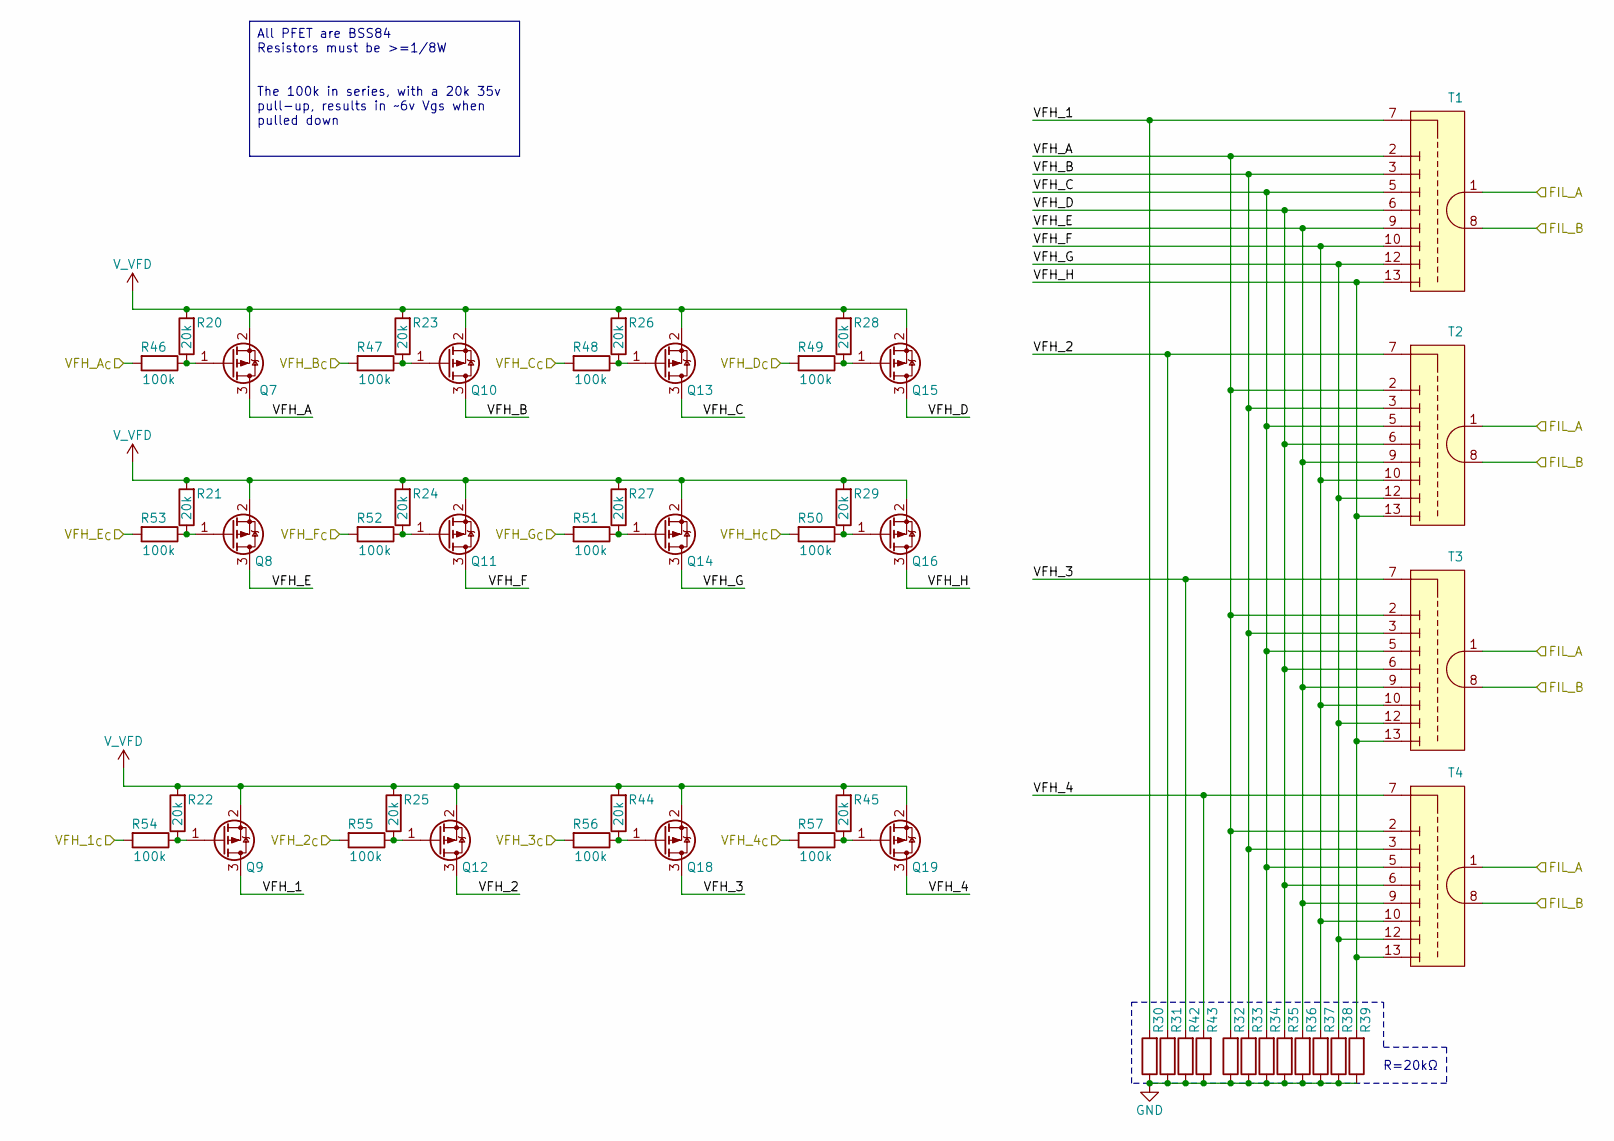
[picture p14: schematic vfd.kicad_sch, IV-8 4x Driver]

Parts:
Q7, Q8, Q9, Q10, Q11, Q12, Q13, Q14, Q15, Q16, Q18, Q19: BSS84; SOT-23
R20, R21, R22, R23, R24, R25, R26, R27, R28, R29, R30, R31, R32, R33, R34, R35, R36, R37, R38, R39, R42, R43, R44, R45: 20k; R_0805_2012Metric
R46, R47, R48, R49, R50, R51, R52, R53, R54, R55, R56, R57: 100k; R_0805_2012Metric
T1, T2, T3, T4: IV-8 Adapter

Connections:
/FIL_A: T1.1, T2.1, T3.1, T4.1; also elsewhere on the board
/FIL_B: T1.8, T2.8, T3.8, T4.8; also elsewhere on the board
/VFD and Xsistors/VFH_1: Q9.3 (D), R30.2, T1.7
/VFD and Xsistors/VFH_2: Q12.3 (D), R31.2, T2.7
/VFD and Xsistors/VFH_3: Q18.3 (D), R42.2, T3.7
/VFD and Xsistors/VFH_4: Q19.3 (D), R43.2, T4.7
/VFD and Xsistors/VFH_A: Q7.3 (D), R32.2, T1.2, T2.2, T3.2, T4.2
/VFD and Xsistors/VFH_A_{C}: R46.2; also elsewhere on the board
/VFD and Xsistors/VFH_B: Q10.3 (D), R33.2, T1.3, T2.3, T3.3, T4.3
/VFD and Xsistors/VFH_B_{C}: R47.2; also elsewhere on the board
/VFD and Xsistors/VFH_C: Q13.3 (D), R34.2, T1.5, T2.5, T3.5, T4.5
/VFD and Xsistors/VFH_C_{C}: R48.2; also elsewhere on the board
/VFD and Xsistors/VFH_D: Q15.3 (D), R35.2, T1.6, T2.6, T3.6, T4.6
/VFD and Xsistors/VFH_D_{C}: R49.2; also elsewhere on the board
/VFD and Xsistors/VFH_E: Q8.3 (D), R36.2, T1.9, T2.9, T3.9, T4.9
/VFD and Xsistors/VFH_E_{C}: R53.2; also elsewhere on the board
/VFD and Xsistors/VFH_F: Q11.3 (D), R37.2, T1.10, T2.10, T3.10, T4.10
/VFD and Xsistors/VFH_F_{C}: R52.2; also elsewhere on the board
/VFD and Xsistors/VFH_G: Q14.3 (D), R38.2, T1.12, T2.12, T3.12, T4.12
/VFD and Xsistors/VFH_G_{C}: R51.2; also elsewhere on the board
/VFD and Xsistors/VFH_H: Q16.3 (D), R39.2, T1.13, T2.13, T3.13, T4.13
/VFD and Xsistors/VFH_H_{C}: R50.2; also elsewhere on the board
/VFH_1_{C}: R54.2; also elsewhere on the board
/VFH_2_{C}: R55.2; also elsewhere on the board
/VFH_3_{C}: R56.2; also elsewhere on the board
/VFH_4_{C}: R57.2; also elsewhere on the board
GND: R30.1, R31.1, R32.1, R33.1, R34.1, R35.1, R36.1, R37.1, R38.1, R39.1, R42.1, R43.1; also elsewhere on the board
unnamed: Q7.1 (G), R20.1, R46.1
unnamed: Q8.1 (G), R21.1, R53.1
unnamed: Q9.1 (G), R22.1, R54.1
unnamed: Q10.1 (G), R23.1, R47.1
unnamed: Q11.1 (G), R24.1, R52.1
unnamed: Q12.1 (G), R25.1, R55.1
unnamed: Q13.1 (G), R26.1, R48.1
unnamed: Q14.1 (G), R27.1, R51.1
unnamed: Q15.1 (G), R28.1, R49.1
unnamed: Q16.1 (G), R29.1, R50.1
unnamed: Q18.1 (G), R44.1, R56.1
unnamed: Q19.1 (G), R45.1, R57.1
V_VFD: Q7.2 (S), Q8.2 (S), Q9.2 (S), Q10.2 (S), Q11.2 (S), Q12.2 (S), Q13.2 (S), Q14.2 (S), Q15.2 (S), Q16.2 (S), Q18.2 (S), Q19.2 (S), R20.2, R21.2, R22.2, R23.2, R24.2, R25.2, R26.2, R27.2, R28.2, R29.2, R44.2, R45.2; also elsewhere on the board

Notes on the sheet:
R=20kΩ
All PFET are BSS84 Resistors must be >=1/8W The 100k in series, with a 20k 35v pull-up, results in ~6v Vgs when pulled down

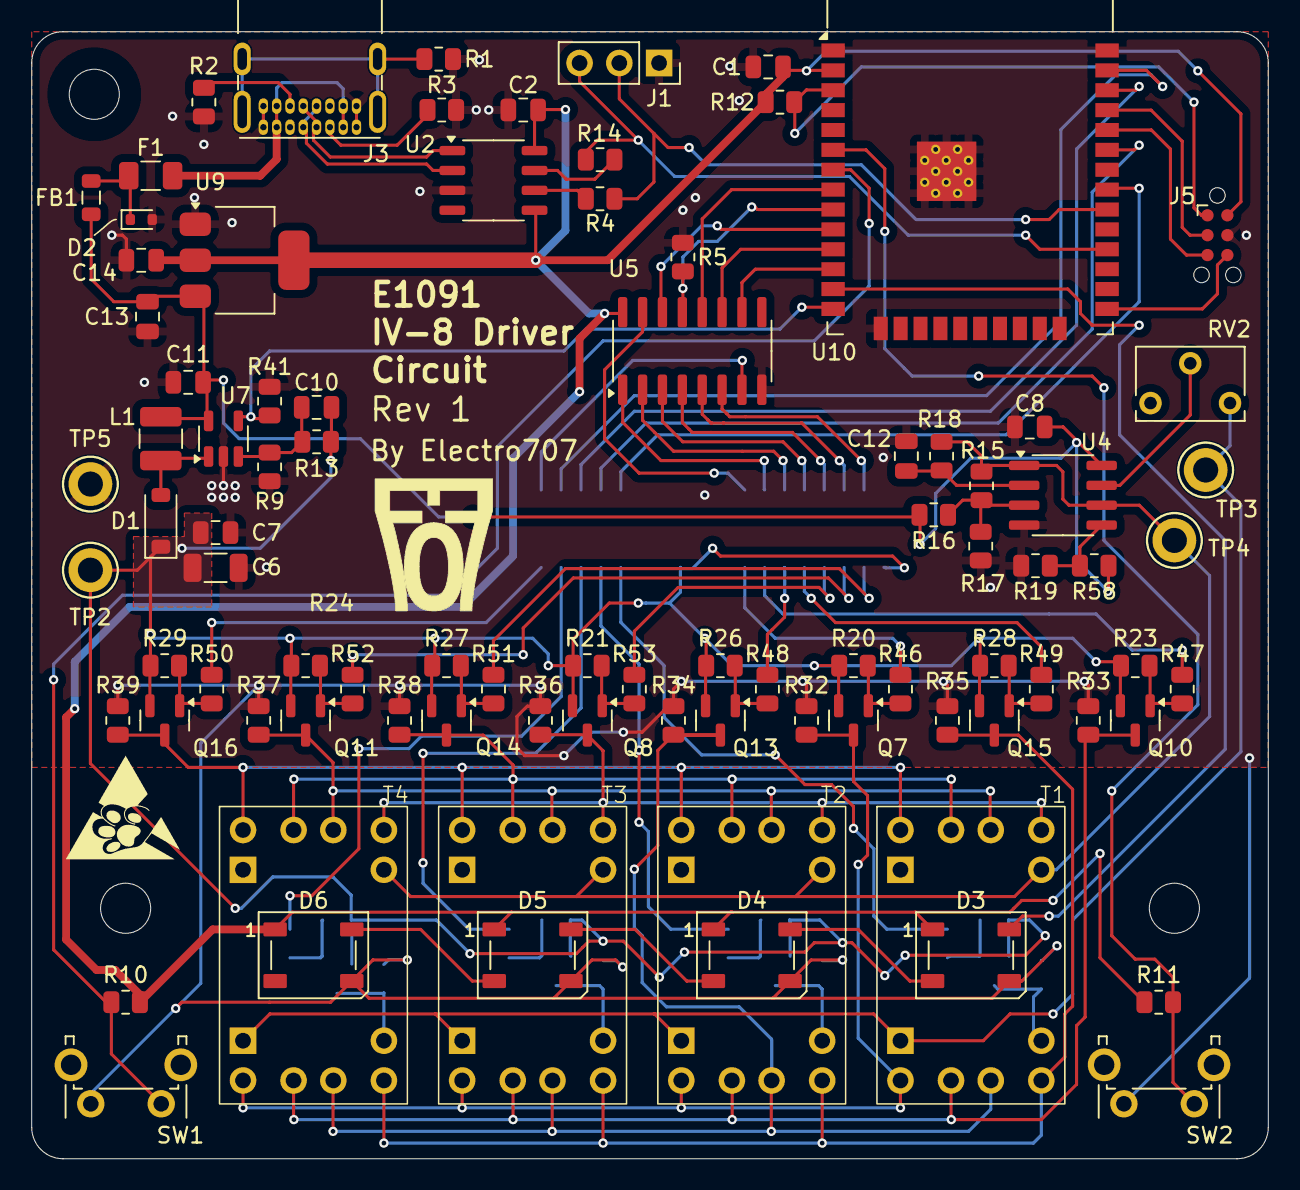
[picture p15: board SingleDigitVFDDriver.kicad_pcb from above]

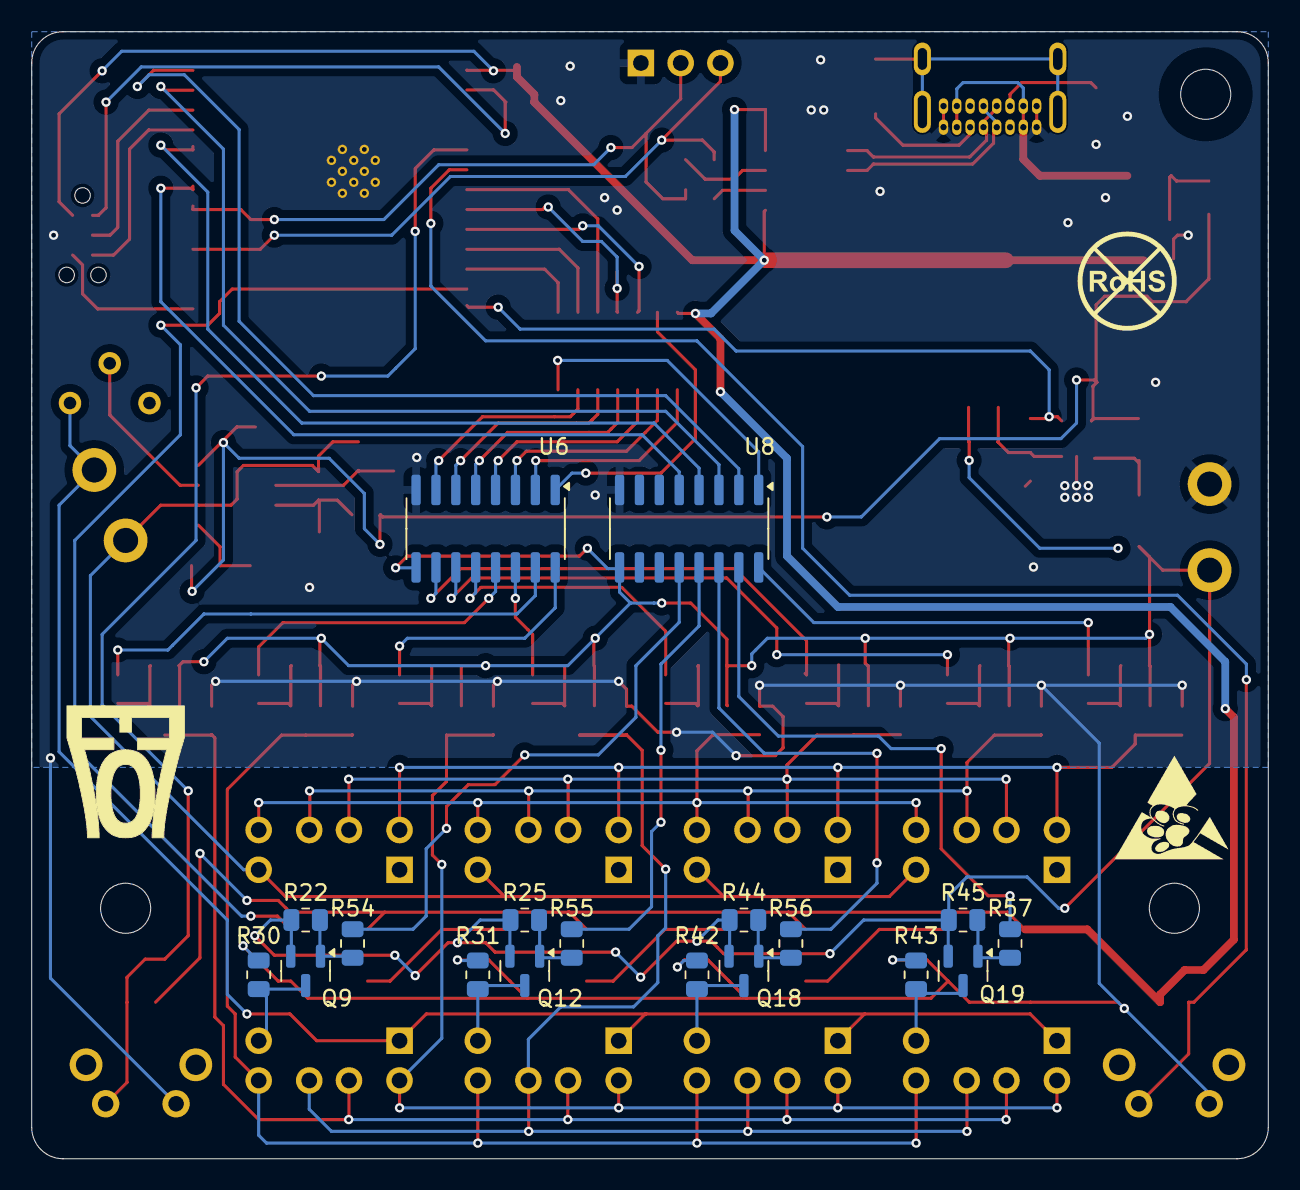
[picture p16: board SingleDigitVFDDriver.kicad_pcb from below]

Board: 2 copper layers, 79.0 x 72.0 mm, 110 parts (18 on the bottom side), 87 nets.

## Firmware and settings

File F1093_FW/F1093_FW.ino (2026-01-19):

// must come before <FastLED.h>
// due to how the RMI interrupts, the SPI backup seems to have less flicker as it uses DMA
#define FASTLED_ALLOW_INTERRUPTS 0
#define FASTLED_ESP32_USE_CLOCKLESS_SPI
#define FASTLED_ESP32_SPI_BUS   HSPI        // use a different SPI than the shift register's VSPI

// #include <SPI.h>
#include <FastLED.h>
#include <WiFi.h>
#include <EEPROM.h>
#include <HardwareSerial.h>
#include <time.h>
#include "common.h"
#include "soc/spi_struct.h"
#include "soc/gpio_struct.h"
#include "soc/dport_reg.h"
/**
 * The file below must be created, which defines DEFAULT_WIFI_SSID and DEFAULT_WIFI_PASSWORD
 */
#include "wifiDefault.h"
#include "comms.h"

char wifiSsid[32];
char wifiPassword[32];

const char* ntpServer = "pool.ntp.org";
const long  gmtOffset_sec = -5*3600;      // Set your timezone offset (e.g., -5*3600 for EST)
const int   daylightOffset_sec = 3600; // Daylight savings (if applicable)

// a look-up betwen display number and enable IO
const uint8_t ioVfdEn[N_DISPLAYS] = {19, 21, 22, 23};
// a look-up between a number to be display and the 7-segment settings
const uint8_t numberToSeg[10] = {0xb7, 0x14, 0x73, 0x76, 0xd4, 0xe6, 0xe7, 0x34, 0xf7, 0xf6};

hw_timer_t *mainTimer;

uint currDisplayedN = 0;     // the current number being displayed. Only to be updated in displayNumber
uint8_t segmentsEnabled[N_DISPLAYS];    // what segments are enabled/on per display

portMUX_TYPE segEnMux = portMUX_INITIALIZER_UNLOCKED;
portMUX_TYPE ledSpinLock = portMUX_INITIALIZER_UNLOCKED;

struct tm currTime;

EEPROMClass nvm("main");

struct led_s leds;

NetworkServer networkServer(23);
NetworkClient networkClient;        // for now only allow one client

HardwareSerial commsSerial(1);

// parser struct for our custom parser
ParserHandler serialParser;
ParserHandler networkParser;

dispMode_e dispMode;
timeFormat_e timeFormat;

TimerHandle_t updateALedT;
TimerHandle_t updateTimeT;

/**
 * This function, called from an interrupt, updates one display at a time every 2Khz
 */
void IRAM_ATTR segmentInterrupt(void){
    static uint32_t currDisp = 0;        // a counter for the current display enabled

    // if we are running ws2812b updates, just bail for this cycle


    // turn off last display
    digitalWrite(ioVfdEn[currDisp], LOW);
    
    // transistion to next display
    currDisp++;
    currDisp &= 0x03;  // equivalent to currDisp %= 4, boolean math magic

    digitalWrite(IO_SHIFT_LDR, LOW);
    // vspi.transfer(segmentsEnabled[currDisp]);

    SPI3.mosi_dlen.usr_mosi_dbitlen = 7;
    SPI3.miso_dlen.usr_miso_dbitlen = 7;

    portENTER_CRITICAL_ISR(&segEnMux);
    SPI3.data_buf[0] = segmentsEnabled[currDisp];
    portEXIT_CRITICAL_ISR(&segEnMux);

    SPI3.cmd.usr = 1;
    while(SPI3.cmd.usr != 0);

    digitalWrite(IO_SHIFT_LDR, HIGH);
    digitalWrite(ioVfdEn[currDisp], HIGH);
}

void setup() {
    Serial.begin(115200);
    // todo: a bit cursed, maybe it will be better to directly handle receive commands.
    //       increasing buffer size for high speed firmware updates
    commsSerial.setRxBufferSize(MAX_FW_BUFFER);
    commsSerial.begin(115200, SERIAL_8N1, COMMS_UART_RX, COMMS_UART_TX);
    DEBUG("initializing");

    // IO init
    pinMode(IO_HIV_EN, OUTPUT);
    pinMode(IO_SHIFT_OE, OUTPUT);
    pinMode(IO_SHIFT_LDR, OUTPUT);
    pinMode(IO_SHIFT_RST, OUTPUT);
    for(int i=0;i<N_DISPLAYS;i++){
        digitalWrite(ioVfdEn[i], LOW);
        pinMode(ioVfdEn[i], OUTPUT);
    }
    // ensure this is HIGH on startup
    digitalWrite(IO_SHIFT_OE, HIGH);

    if (!nvm.begin(0x200)) {
        // todo: this came from their example. is restarting the best?
        DEBUG("Failed to initialize nvm");
        DEBUG("Restarting...");
        delay(1000);
        ESP.restart();
    }
    
    // we have an empty nvm, initialize
    if(nvm.read(0) != NVM_MAGIC){
        strcpy(wifiSsid, DEFAULT_WIFI_SSID);
        strcpy(wifiPassword, DEFAULT_WIFI_PASSWORD);
    }

    // set variables
    memset(segmentsEnabled, 0x40, sizeof(segmentsEnabled));
    leds.ledBlinkMode = LED_BLINK_MODE_SEC;
    leds.ledColorMode = LED_MODE_TIME_HUE;
    timeFormat = TIME_FORMAT_24HR;
    
    // vspi.begin(IO_SHIFT_CLK, -1, IO_SHIFT_DAT, -1);
    // vspi.setHwCs(false);
    // vspi.beginTransaction(SPISettings(spiClk, MSBFIRST, SPI_MODE0));

    GPIO.enable |= (1 << IO_SHIFT_CLK) | (1 << IO_SHIFT_DAT);
    GPIO.func_out_sel_cfg[IO_SHIFT_DAT].val = 65 | (1 << 10);
    GPIO.func_out_sel_cfg[IO_SHIFT_CLK].val = 63 | (1 << 10);
    REG_WRITE(IO_MUX_GPIO25_REG, 0x2801);
    REG_WRITE(IO_MUX_GPIO26_REG, 0x2801);

    DPORT_SET_PERI_REG_MASK(DPORT_PERIP_CLK_EN_REG, DPORT_SPI3_CLK_EN);
    SPI3.pin.val = 0b111;
    SPI3.pin.ck_idle_edge = 1;
    SPI3.user.usr_command = 0;
    SPI3.user.usr_mosi = 1;
    SPI3.user.doutdin = 1;

    SPI3.ctrl2.miso_delay_mode = 2;
    SPI3.clock.clkdiv_pre = 59;
    SPI3.clock.clkcnt_n = 3;
    SPI3.clock.clkcnt_h = 1;
    SPI3.clock.clkcnt_l = 3;
    SPI3.clock.clk_equ_sysclk = 0;

    // reset shift register
    digitalWrite(IO_SHIFT_RST, LOW);
    digitalWrite(IO_SHIFT_LDR, LOW);
    delay(10);
    digitalWrite(IO_SHIFT_RST, HIGH);
    digitalWrite(IO_SHIFT_LDR, HIGH);
    digitalWrite(IO_SHIFT_OE, LOW);
    // enable high voltage boost converter
    digitalWrite(IO_HIV_EN, HIGH);

    // setup wifi
    WiFi.setHostname(NETWORK_HOSTNAME);
    WiFi.onEvent(WiFiEvent);
    WiFi.config(INADDR_NONE, INADDR_NONE, INADDR_NONE, INADDR_NONE);
    WiFi.begin(wifiSsid, wifiPassword);

    // setup LEDs
    FastLED.addLeds<WS2812, IO_ADDR_LED>(leds.leds, NUM_ADDR_LEDS);
    
    // setup comms
    serialParser.setPrintClass(&commsSerial);
    // network setup happens on connection

    // setup tasks
    // because the updating of the segments is critical, we use an old fashioned interrupt    
    mainTimer = timerBegin(1000000);
    timerAttachInterrupt(mainTimer, &segmentInterrupt);
    timerAlarm(mainTimer, 500, true, 0);
    // for the rest of the stuff, they can run with a decent amount of jitter/deviation
    updateTimeT = xTimerCreate("updateTimeT", pdMS_TO_TICKS(250), true, NULL, updateTimeCallback);
    updateALedT = xTimerCreate("updateALedT", pdMS_TO_TICKS(50), true, NULL, updateLED);
    xTimerStart(updateALedT, 0);

    setDisplayMode(DISPLAY_MODE_TIME);

    DEBUG("postBegin");
}

// void onConnect(arduino_event_t *e){
//     Serial.print("Obtained IP address: ");
//     Serial.println(WiFi.localIP());

//     configTime(gmtOffset_sec, daylightOffset_sec, ntpServer);
// }

void WiFiEvent(WiFiEvent_t event) {
    // todo: clean up the case statements as needed
    DEBUG("[WiFi-event] event: %d\n", event);

    switch (event) {
        case ARDUINO_EVENT_WIFI_READY:               DEBUG("WiFi interface ready"); break;
        case ARDUINO_EVENT_WIFI_SCAN_DONE:           DEBUG("Completed scan for access points"); break;
        case ARDUINO_EVENT_WIFI_STA_START:           DEBUG("WiFi client started"); break;
        case ARDUINO_EVENT_WIFI_STA_STOP:            DEBUG("WiFi clients stopped"); break;
        case ARDUINO_EVENT_WIFI_STA_CONNECTED:       DEBUG("Connected to access point"); break;
        case ARDUINO_EVENT_WIFI_STA_DISCONNECTED:    DEBUG("Disconnected from WiFi access point"); break;
        case ARDUINO_EVENT_WIFI_STA_AUTHMODE_CHANGE: DEBUG("Authentication mode of access point has changed"); break;
        case ARDUINO_EVENT_WIFI_STA_GOT_IP:
            DEBUG("Obtained IP address: %s", WiFi.localIP().toString().c_str());
            configTime(gmtOffset_sec, daylightOffset_sec, ntpServer);
            networkServer.begin();
            networkServer.setNoDelay(true);
            break;
        case ARDUINO_EVENT_WIFI_STA_LOST_IP:
            DEBUG("Lost IP address and IP address is reset to 0");
            networkServer.end();
            break;
        case ARDUINO_EVENT_WPS_ER_SUCCESS:          DEBUG("WiFi Protected Setup (WPS): succeeded in enrollee mode"); break;
        case ARDUINO_EVENT_WPS_ER_FAILED:           DEBUG("WiFi Protected Setup (WPS): failed in enrollee mode"); break;
        case ARDUINO_EVENT_WPS_ER_TIMEOUT:          DEBUG("WiFi Protected Setup (WPS): timeout in enrollee mode"); break;
        case ARDUINO_EVENT_WPS_ER_PIN:              DEBUG("WiFi Protected Setup (WPS): pin code in enrollee mode"); break;

        case ARDUINO_EVENT_WIFI_AP_START:           DEBUG("WiFi access point started"); break;
        case ARDUINO_EVENT_WIFI_AP_STOP:            DEBUG("WiFi access point  stopped"); break;
        case ARDUINO_EVENT_WIFI_AP_STACONNECTED:    DEBUG("Client connected"); break;
        case ARDUINO_EVENT_WIFI_AP_STADISCONNECTED: DEBUG("Client disconnected"); break;
        case ARDUINO_EVENT_WIFI_AP_STAIPASSIGNED:   DEBUG("Assigned IP address to client"); break;
        case ARDUINO_EVENT_WIFI_AP_PROBEREQRECVED:  DEBUG("Received probe request"); break;
        case ARDUINO_EVENT_WIFI_AP_GOT_IP6:         DEBUG("AP IPv6 is preferred"); break;
        case ARDUINO_EVENT_WIFI_STA_GOT_IP6:        DEBUG("STA IPv6 is preferred"); break;
        default:                                    break;
    }
}

void loop() {
    // handle new client connections
    if (networkServer.hasClient()) {
        if(networkClient.connected()){
            networkServer.accept().stop();
        } else {
            networkClient = networkServer.accept();
            networkParser.setPrintClass(&networkClient);
            DEBUG("New client: %s", networkClient.remoteIP().toString().c_str());
        }
    }
    // client read loop
    if(networkClient.connected()){
        while(networkClient.available()){
            networkParser.parse(networkClient.read());
        } 
    }

    while(commsSerial.available()){
        serialParser.parse(commsSerial.read());
    }
}

// handles the transition in the display mode
void setDisplayMode(dispMode_e newMode){
    dispMode = newMode;
    
    if(newMode == DISPLAY_MODE_TIME){
        xTimerStart(updateTimeT, 0);
    } else {
        xTimerStop(updateTimeT, 0);
    }

    if(newMode == DISPLAY_MODE_OFF){
        portENTER_CRITICAL(&segEnMux);
        for(int i=0;i<N_DISPLAYS;i++){
            segmentsEnabled[i] = 0;
        }
        portEXIT_CRITICAL(&segEnMux);
    }
}

void updateTimeCallback(TimerHandle_t xTimer){
    uint currTimeN;
    time_t now;
    float tmp;

    // basically doing the same as getLocalTime in `esp32-hal-time.c`, but no timeout. if it fails it fails
    time(&now);
    localtime_r(&now, &currTime);
    if (currTime.tm_year > (2016 - 1900)) {
        switch(timeFormat){
            case TIME_FORMAT_24HR:
                currTimeN = currTime.tm_min + (currTime.tm_hour*100);
                break;
            case TIME_FORMAT_12HR:
                currTimeN = currTime.tm_min + ((currTime.tm_hour % 12)*100);
                break;
            case TIME_FORMAT_METRIC:
                // get the current time as a proportion of the day
                tmp = currTime.tm_sec + (60.0*(float)currTime.tm_min) + (3600.0*(float)currTime.tm_hour);
                tmp /= 86400;
                // now start dividing and filling the hours and minutes spot
                tmp *= 10;
                currTimeN = (uint)floor(tmp);
                tmp -= currTimeN;
                currTimeN *= 100;       // convert the hours to the 100's decimal place
                tmp *= 100;
                currTimeN += (uint)floor(tmp);
                break;
        }
        
        displayNumber(currTimeN);
    }
}

void updateLED(TimerHandle_t xTimer){
    static CHSV toSet = CHSV(0, 255, 128);
    CRGB toSetRgb;
    float tmp;

    switch(leds.ledColorMode){
        case LED_MODE_RAINBOW:
            toSet.h += 1;
            hsv2rgb_spectrum(toSet, toSetRgb);
            fill_solid(leds.leds, NUM_ADDR_LEDS, toSetRgb);
            break;
        case LED_MODE_TIME_HUE:
            tmp = (float)currTime.tm_sec;
            tmp /= 60;
            tmp *= 256;
            toSet.h = (uint8_t)tmp;
            hsv2rgb_spectrum(toSet, toSetRgb);
            fill_solid(leds.leds, NUM_ADDR_LEDS, toSetRgb);
            break;
        default:
            break;
    }

    switch(leds.ledBlinkMode){
        case LED_BLINK_MODE_OFF:
            break;
        case LED_BLINK_MODE_SEC:
            // turn the whole LED set off once every other odd second
            if((currTime.tm_sec % 2) == 0){
                fill_solid(leds.leds, NUM_ADDR_LEDS, CRGB::Black);
            }
            break;
        default:
            break;
    }

    taskENTER_CRITICAL(&ledSpinLock);
    FastLED.show();
    taskEXIT_CRITICAL(&ledSpinLock);
}

// displays a new number
void displayNumber(uint n){
    const uint power10[N_DISPLAYS] = {1, 10, 100, 1000};
    uint toS;

    portENTER_CRITICAL(&segEnMux);
    for(int i=0;i<N_DISPLAYS;i++){
        // only remove the zeros if we are displaying a number (todo: maybe just exclude time from this)
        if(dispMode == DISPLAY_MODE_NUMB){
            if(n < power10[i]){
                segmentsEnabled[i] = 0;
                continue;
            }
        }
        toS = n / power10[i];
        toS %= 10;
        segmentsEnabled[i] = numberToSeg[toS];
    }
    portEXIT_CRITICAL(&segEnMux);

    currDisplayedN = n;      // update global variable
}

void saveNvm(void){
    nvm.writeByte(0, NVM_MAGIC);
    nvm.writeBytes(1, wifiSsid, 32);
    nvm.writeBytes(1, wifiPassword, 32);
    nvm.commit();
}

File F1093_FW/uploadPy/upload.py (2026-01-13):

#!/bin/python
"""
A python script to update the F1093 firmware with a given binary file exported from Arduino
"""
import time

import serial
import argparse
from pathlib import Path
import logging
import os


class Update:
    chunkSize = 8192

    def __init__(self, port):
        self.log = logging.getLogger('updater')
        self.ser = serial.Serial(port, 115200, timeout=1)

    def checkPing(self):
        self._writeSer('ping')
        r = self._readLine()
        if r != 'pong!':
            return False
        return True

    def setUartBaud(self, newBaud: int):
        self._writeSerAck(f'set uartBaud {newBaud:d}')
        self.ser.flush()
        self.ser.baudrate = newBaud

    def setTimeMode(self, newMode: int):
        self._writeSerAck(f'set mode {newMode:s}')

    def setLedColorMode(self, newMode: str):
        self._writeSerAck(f'set ledColor {newMode:s}')

    def reset(self):
        self._writeSer('reboot')

    def update(self, file: Path):
        if not os.path.isfile(file):
            self.log.warning("file given is not a file")
            return False

        f = open(file, 'rb')
        try:
            binLen = os.path.getsize(file)

            # in case we had a previous on-going firmware update
            self._writeSerAck(f"update cancel")

            stat = self._writeSerAck(f"update begin {binLen:d}")
            if not stat:
                self.log.warning("unable to init update")
                return False

            while binLen > 0:
                toSend = min(self.chunkSize, binLen)

                stat = self._writeSerAck(f"update cont {toSend:d}")
                if not stat:
                    self.log.warning("unable to continue update")
                    return False
                # now we send the raw bytes
                self.ser.write(f.read(toSend))
                stat = self._waitForAck()
                if not stat:
                    self.log.warning("unable to continue update")
                    return False

                binLen -= toSend

            stat = self._writeSerAck(f"update end")
            if not stat:
                self.log.warning("unable to finish update")
                return False

            return True
        finally:
            f.close()

    def _writeSerAck(self, s: str):
        self._writeSer(s)
        return self._waitForAck()

    def _waitForAck(self):
        r = self._readLine()
        if r != 'ok':
            self.log.warning(f"did not return ok: {r}")
            return False
        return True

    def _writeSer(self, s: str):
        self.log.debug(f"-> {s}")
        self.ser.write(s.encode()+b'\n')

    def _readLine(self) -> str:
        r = self.ser.read_until()
        r = r.decode().strip()
        self.log.debug(f"<- {r}")
        # time.sleep(0.1)
        return r


def main():
    parser = argparse.ArgumentParser()
    parser.add_argument("file", type=Path, help="path to firmware file")
    parser.add_argument("ser", type=str, help="serial port")
    args = parser.parse_args()

    u = Update(args.ser)
    if not u.checkPing():
        print("Device did not repond with pong!")
        return
    # when updating, presumably the ISR shuts off during flash writting, causes the tubes flash a bit
    #   so better to turn the display off when updating
    u.setTimeMode('off')
    u.setLedColorMode('off')
    u.setUartBaud(921600)
    stat = u.update(args.file)
    if not stat:
        print("Unable to update firmware")
    else:
        u.reset()


if __name__ == "__main__":
    logging.basicConfig(level=logging.DEBUG)

    main()

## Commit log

2025-05-03 Initial Release
    [Assembly.FCStd, B1094.FCStd, B1094Rev1.stl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]
2025-07-19 Renamed file
    [C1094.FCStd]
2025-07-19 Renamed B prefix to C for exported parts
    [C1094Rev1.stl, C1095Rev1.3mf, C1095Rev1.stl]
2025-07-30 Added button piece to be able to press the buttons
    [Assembly.FCStd, C1094.FCStd, C1096Rev1.stl]
2025-10-05 Started testing light-pipe
    [C1094.FCStd]
2026-01-05 Added errata document, describing the op-amp fix
    [E1091_BOM.csv]
2026-01-13 updated SPI to use registers directly made ISR to run from IRAM added LED Modes and LED color config Updated Docs
2026-01-19 Fixed no-blink mode. improved ws2812 flickering issue
    [F1093_FW.ino]
2026-02-16 Fixed BOM diode to correct one
    [E1091_BOM.csv]
